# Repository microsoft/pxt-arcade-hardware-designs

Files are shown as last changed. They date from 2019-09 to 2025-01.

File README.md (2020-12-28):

# MakeCode Arcade Hardware Designs

This repository houses hardware reference design information for MakeCode Arcade devices. See https://arcade.makecode.com/hardware/adding for more information.

# Project List

- ArcadeMVD-STM: Standalone MakeCode Arcade gaming console based on STM32F4
- microbit-shield: MakeCode Arcade 'shield' for use with micro:bit V2

# Contributing

This project welcomes contributions and suggestions.  Most contributions require you to agree to a
Contributor License Agreement (CLA) declaring that you have the right to, and actually do, grant us
the rights to use your contribution. For details, visit https://cla.microsoft.com.

When you submit a pull request, a CLA-bot will automatically determine whether you need to provide
a CLA and decorate the PR appropriately (e.g., label, comment). Simply follow the instructions
provided by the bot. You will only need to do this once across all repos using our CLA.

This project has adopted the [Microsoft Open Source Code of Conduct](https://opensource.microsoft.com/codeofconduct/).
For more information see the [Code of Conduct FAQ](https://opensource.microsoft.com/codeofconduct/faq/) or
contact [opencode@microsoft.com](mailto:opencode@microsoft.com) with any additional questions or comments.

# Legal Notices

Microsoft and any contributors grant you a license to the Microsoft documentation and other content
in this repository under the [Creative Commons Attribution 4.0 International Public License](https://creativecommons.org/licenses/by/4.0/legalcode),
see the [LICENSE](LICENSE) file, and grant you a license to any code in the repository under the [MIT License](https://opensource.org/licenses/MIT), see the
[LICENSE-CODE](LICENSE-CODE) file.

Microsoft, Windows, Microsoft Azure and/or other Microsoft products and services referenced in the documentation
may be either trademarks or registered trademarks of Microsoft in the United States and/or other countries.
The licenses for this project do not grant you rights to use any Microsoft names, logos, or trademarks.
Microsoft's general trademark guidelines can be found at http://go.microsoft.com/fwlink/?LinkID=254653.

Privacy information can be found at https://privacy.microsoft.com/en-us/

Microsoft and any contributors reserve all others rights, whether under their respective copyrights, patents,
or trademarks, whether by implication, estoppel or otherwise.

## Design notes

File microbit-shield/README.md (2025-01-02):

Picture of micro:bit MakeCode Arcade shield (https://youtu.be/uZcsJYvYL_I)

# MakeCode Arcade Shield for micro:bit V2 Specification

**Preliminary, untested design; see below for more details. License: CC-BY 4.0.**

Thank you for your interest in building a [MakeCode Arcade](https://arcade.makecode.com/)
shield for the [new micro:bit V2](https://tech.microbit.org/latest-revision/announcement/).
We hope that you are as excited as we are to bring a wealth of new experiences to users of micro:bit V2 and MakeCode Arcade.

**Arcade Shields will work only with micro:bit V2**; they will not work with the original micro:bit V1.

To enable a diverse ecosystem of Arcade shields for the micro:bit V2 while maintaining a cohesive user experience, 
it is important to standardize software and hardware interfaces.
We have therefore produced a specification along with hardware and firmware reference designs that describe the compatibility
requirements for a MakeCode Arcade display shield for micro:bit V2.
Any shield that is produced must be approved by Microsoft and The Micro:bit Educational Foundation before
it will be publicly listed.

A [PDF schematic](https://raw.githubusercontent.com/microsoft/pxt-arcade-hardware-designs/master/microbit-shield/MicroBitArcadeShieldMVD%2008-1.2.PDF)
of our hardware reference design is available in this folder.
If you view this with Adobe Reader
then clicking on the symbol of each component in the design will show the manufacturer name and part number plus other
details. Other PDF viewing software may not support this feature.

The preliminary information here is provided as a request for comments:
please use the [discussions tab](https://github.com/microsoft/pxt-arcade-hardware-designs/discussions)
or [file an issue](https://github.com/microsoft/pxt-arcade-hardware-designs/issues) in this repo to provide further comments and feedback.

**NOTICE:
This information is provided “as-is”.
You bear the risk of using it.
Aspects of the specification may change without notice.
Microsoft makes no warranties, express or implied, with respect to the information provided here.**

Structure of this document:
- [Desired End-user Experience](#user-experience)
- [Two Ways to Implement an Arcade Shield](#types-shields)
- [Simple Shield Details](#hdw-config)
- [Power](#power)
- [Jacdac](#jacdac)
- [MCU Shield Details](#smart-shield)
- [Arcade Shield Testing](#testing)

## Desired End-user Experience

We want to create an intuitive, simple, reliable and engaging experience for end-users of MakeCode Arcade and micro:bit V2. A user first programs a game at https://arcade.makecode.com/, then clicks the Download
button, selects "micro:bit (V2) with shield" from the dialog (there is only one
entry for all micro:bit shields), and drops the resulting `.hex` file onto the `MICROBIT` drive of their micro:bit V2.
The user can plug their micro:bit V2 into an Arcade shield to play the game.

The micro:bit V2 can be also programmed when plugged into a shield, in which case batteries are not needed in the shield.

## Two Ways to Implement an Arcade Shield

There are two ways to implement an Arcade shield:
- A **simple shield**'s hardware components are all driven directly from the micro:bit V2; the shield itself has no additional microcontroller. The simple shield supports only 128x160 pixel ST7735/ILI9163C SPI screens, which are typically ~1.8" diagonal.
- An **MCU shield** or **smart shield** is fitted with a microcontroller (MCU) that provides a consolidated SPI interface to the micro:bit V2, and may drive a range of different screens including those with an 8-bit parallel connection. The micro:bit uses this SPI interface to update the shield’s display and to support other inputs and outputs such as buttons. MCU shield designers may choose to leverage additional capabilities of the on-shield MCU to attach additional peripherals via GPIOs, I2C or otherwise.

## Simple Shield Details

* [PDF schematics](https://raw.githubusercontent.com/microsoft/pxt-arcade-hardware-designs/master/microbit-shield/MicroBitArcadeShieldMVD%2008-1.2.PDF) of the reference design
* [Bill of Materials](https://github.com/microsoft/pxt-arcade-hardware-designs/blob/master/microbit-shield/BOM%20(complete%20design)%20MicroBitArcadeShieldMVD%2008-1.2.xlsx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)

As its name suggests, the design of a Simple Shield is straightforward. The micro:bit V2 edge connector 
SPI lines drive the display module directly, although simple low-pass RC filters are likely to be required 
on the SPI data and clock lines to reduce EMI. 
A discrete transistor is used to control the display backlight because a micro:bit GPIO would not be able to 
source the necessary current, ~45mA. 

To reduce the number of micro:bit GPIOs required to interface to
the Arcade control buttons, the reference design for the Simple Shield contains two parallel in, serial 
out shift registers (`INSR0` and `INSR1`). By being economical with micro:bit GPIOs, the three 'ring' GPIOs (P0, P1 and P2) are left available for users to connect to.

There are different variants of 128x160 pixel ST7735/ILI9163C SPI screens, so the MakeCode Arcade software stack needs to determine which is used by a
particular Arcade Shield and its orientation in order to perform the appropriate software configuration.
At power on, the MakeCode Arcade software stack inspects the upper most four bits of
the second input shift register (inputs `HW_CFG0` – `HW_CFG3` of `INSR1`) to determine hardware configuration.
A valid identifier stored in these bits allows the Arcade software stack to perform the appropriate software configuration.

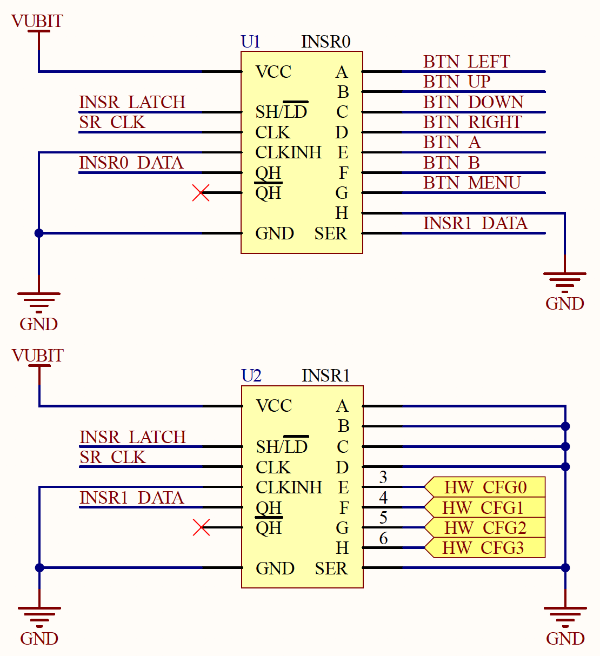
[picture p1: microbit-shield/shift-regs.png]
input shift registers picture


To set a `HW_CFGx` pin to a zero or one, it must be pulled low (to `GND`) or high (to `VUBIT`).
The reference design includes three-way solder jumpers for experimentation.
The tables below summarize the currently-supported hardware configuration identifiers.
If you would like to propose a new configuration please [file an issue in this repo](https://github.com/microsoft/pxt-arcade-hardware-designs/issues).

| `HW_CFG0` | Display rotation
|---:|---
| 0 | Display rotated 180 degrees; screen's flat-flex is on the left.
| 1 | Display not rotated; screen's flat-flex is on the right.

| `HW_CFG3` | `HW_CFG2` | `HW_CFG1` | Hardware configuration
|---:|---:|---:| ---
| 0 | 0 | 0 | Reserved, do not use
| 0 | 0 | 1 | ST7735 (`CFG1=0x603` or `CFG1=0x12c2d`; most common)
| 0 | 1 | 0 | ILI9163C with BGR color order (`CFG1=0xe14ff`)
| 0 | 1 | 1 | ST7735 with inverted color values (`CFG1=0x603`, `CFG0 = 0x1??????`)
| 1 | 0 | 0 | Future configuration (micro:bit will hang)
| 1 | 0 | 1 | Future configuration (micro:bit will hang)
| 1 | 1 | 0 | Future configuration (micro:bit will hang)
| 1 | 1 | 1 | Reserved, do not use

Our reference design includes two options for controlling the CS ('chip select') input on a typical SPI display such as one integrating an ST7735 controller IC. These options are selected via a solder-blob jumper, SB4 on the schematic. The simplest approach is to hard-wire CS to logic zero, so that the display is permanently enabled. However, in this case the display may be susceptible to latch-up as a result of an ESD event, and therefore may not pass EMC compliance testing. [Kitronik Ltd](https://kitronik.co.uk/) have kindly contributed an alternative approach to controlling the display's CS input, which causes the display to be automatically de-selected after every frame update and then re-selected a short time later, in time for the next frame of data. Kitronik's circuit ("Dynamic display enable generator" in the reference design) uses two monostable circuits, each consisting of a capacitor, transistor and some resistors. The first monostable is designed to introduce a ~20μs delay following the end of a burst of SPI clock activity, while the second is a ~5-10μs pulse generator that drives the CS input via a final transistor inverter.

## Power

The shield sources power directly from the micro:bit V2 when the micro:bit is powered from USB, 
whether connected to a USB power supply or connected to a computer.
When the micro:bit is not being powered from USB, a battery/batteries fitted to the shield can be used to power both shield and micro:bit.

In our reference design the shield incorporates 3x AA cells and a low dropout linear regulator to generate 3.3V. 
This passes through a 300mΩ series resistor to reduce the voltage to around 3.25V, depending on current draw.
(Conveniently there is already a 300mΩ ferrite on the design to reduce EMI, so we use a second of these rather 
than adding a new component to the BoM.)
Since the micro:bit will provide exactly 3.3V on its edge connector when powered from USB,
current for the shield will be sourced from this USB power when it is provided. But when the micro:bit is disconnected from USB power,
the shield's regulated battery supply of 3.25V will be used, giving users an uninterrupted experience as they move to on-the-go gaming.

The reference design draws no battery power if the micro:bit is not inserted into the Arcade shield.
This is achieved by connecting `VBAT_GND` to the shield’s `GND` through the micro:bit edge connector, so a circuit is completed only when a micro:bit has been inserted into the shield.

While the reference design uses 3x AA cells, alternative power sources such as rechargeable batteries are possible. Please be sure to meet all relevant safety and compliance guidelines. If using a detachable battery or battery pack, please use a connector that is different from the micro:bit 3V battery pack connector to avoid confusion and potential damage to the shield or micro:bit. **Please do not use batteries that can be swallowed, such as coin cells.** 

If the Arcade Shield does not have batteries fitted and the micro:bit is powered from 2xAA batteries (instead of via USB), at most 3.0V will be available, and without fresh batteries significantly less. This should be
avoided because shield operation will be unreliable; in particular the display backlight may not function correctly.

When a micro:bit is running a game and the Arcade shield screen is at full brightness the power draw should be ~45mA for a 1.8"
screen, ~100mA for a 2.4" screen and slightly more for 2.8" and 3.2" screens. When the micro:bit is disconnected from the shield no power is drawn.

## Jacdac

[Jacdac](https://aka.ms/jacdac) is a plug-and-play protocol and hardware/software stack for connecting microcontrollers and peripherals, developed by Microsoft and Lancaster University. Jacdac's flexible topology supports dynanic discovery and power delivery, thereby providing
an intuitive and low-cost way for users to extend their physical computing devices and projects with new hardware. 
Microsoft provides a first-class Jacdac experience in MakeCode that integrates the auto-detection, programming, simulation and operation of Jacdac devices.

Jacdac uses three wires to support 1Mbps half-duplex serial communications at 3.3V logic levels and power delivery of up to 1A at 5V. It uses a purpose-designed 3-pin PCB edge connector in conjunction with easy-to-use cables. It is a true bus topology that allows multiple devices to be connected directly to the same bus, but unlike I2C all devices have unique IDs.

When a micro:bit is plugged into an Arcade shield, the micro:bit edge connector is no longer available
for other accessories. However, it's still possible to support a physical computing experience if the Arcade shield supports Jacdac.
For this reason, the reference design includes two [Jacdac edge connectors](https://github.com/microsoft/jacdac-mdk/tree/main/connector). 
Users of shields that include Jacdac support will be able to use commercially-available Jacdac modules.

A set of [specifications](https://microsoft.github.io/jacdac-docs/ddk/) and [reference designs](https://github.com/microsoft/jacdac-ddk) for building Jacdac modules is availalbe.

To support the Jacdac experience, the Arcade shield requires additional components, as indicated in the reference design. 
Minimally, three diodes, a capacitor, a resistor and a ferrite bead are needed to support Jacdac communications. However,
for the best user experience an additional low-cost DC-DC converter and low-cost current limiter (plus support circuitry) 
can be included. These components allow the Arcade shield to safely and reliably provide power to the Jacdac bus. 
This in turn allows end users
to plug in sensor, display and actuator modules without worrying about power.

Power delivered to the Jacdac bus is always controlled by a current limiting circuit. For the Arcade shield we suggest
using one of several readily-available and low-cost 75mA (typical) current limiter ICs since these are a good match with
the supply available from the micro:bit. These ICs have an absolute maximum current limit of up to 100mA. 
The voltage at the Jacdac PCB edge connector on the Arcade shield must be between 
3.67V (absolute minimum) and 5.5V (absolute maximum) when the current can reach a maximum of 100 mA. For lower maximum currents, a lower minimum voltage is permissible, see [Vout_pp](https://microsoft.github.io/jacdac-docs/reference/electrical-spec/#power-providers). 
In our reference design, which uses a Schottky diode to prevent back-powering, in order to ensure at least 3.67V at the Jacdac connector, the input to the current limiter must be at least 3.88V. It is possible to supply power from 3x AA batteries but note that when they fall below ~1.3V each the device will be out of spec for a 100mA Jacdac power provider. It is also possible to supply power from a LiPo battery but again, when its terminal voltage falls below 3.88V it will be out of spec for delivering 100mA. An ideal diode with a lower forward voltage drop than the Schottky diode in our reference design will provide more margin. Note that **a current limiter must be used** in all cases.

It is also possible for an Arcade display shield to provide in excess of 100mA, which must be done 
at a slightly higher voltage, again please refer to [Vout_pp](https://microsoft.github.io/jacdac-docs/reference/electrical-spec/#power-providers). In this case **the shield must contain a microcontroller running the [Jacdac power service](https://microsoft.github.io/jacdac-docs/services/power/)**.  

## MCU Shield Details

An MCU Shield contains an MCU that interfaces with the attached micro:bit V2 using
a form of the [Jacdac protocol](https://aka.ms/jacdac), run over SPI.
It exposes at least two Jacdac services, one for driving the screen, and one for reading the buttons.
Additional services can be added for peripherals like vibration motors. The MCU Shield is therefore
more complicated to design and produce than the Simple Shield, but it supports more features, including larger screens.

The MCU Shield typically drives a 320x240 screen based on the ILI9341 chip, using an 8 bit parallel connection.
The Jacdac screen interface uses the Arcade's native 160x120 resolution and 4 bit indexed color depth, 
so the 4MHz SPI bus between the shield and the micro:bit is enough to obtain smooth frame rates.
The Shield MCU up-scales to 320x240 and converts from 
4 bit color to the 12, 16 or 18 bit RGB color typically used by the screens.
Other controller chips (such as S6D0154, ILI9325, ST7789) can by supported
with slight modifications of the MCU firmware. With more extensive firmware modification yet more
screen configurations are possible.
It's even possible to connect to an ST7735 controller over SPI, with all of that being abstracted by the Jacdac screen interface.
We have prototyped MCU Shields with some of these configurations.

An MCU Shield requires no input shift registers,
instead the micro:bit edge connector pin allocated to `INSR0_DATA` must be pulled high while the MakeCode Arcade software stack initializes the shield MCU.
This results in the MakeCode Arcade software stack reading a sequence of sixteen ones, which indicates that an MCU Shield is connected.
Additional detection and configuration will then take place over SPI from the micro:bit.

### Reference Firmware Designs

We provide MCU Shield reference firmware for the STM32F030 chips (popular ones include STM32F030K6, STM32F030C6 and STM32F030C8).
The 8-bit parallel connection is bit-banged, so STM32F030x6 can be used.
The firmware can be easily adapted to STM32F031, STM32G030, STM32G031 and possibly others.
If you want to drive a 1.77" ST7735 via SPI note that only STM32G03x and STM32F030C8 have dual SPI.

The reference firmware can be found at https://github.com/microsoft/pxt-arcade-smart-shield.
There are instructions for building and modifying it in the firmware repository.

### Reference Hardware Designs

The [PDF file](https://raw.githubusercontent.com/microsoft/pxt-arcade-hardware-designs/master/microbit-shield/smart-shield-v0.0.1.pdf) 
in this folder shows changes between the Simple and MCU Shields in schematic form.
Essentially:
* the input shift registers are replaced with an MCU, which is then connected to the screen;
* button pull-ups are removed sicne the MCU has internal pull-ups;
* more pins are left free on the edge connector, including the SCL/SDA pins;
* the circuity for the power supply, JACDAC, and the external P0, P1 and P2 rings stays the same.

You will also need to connect an SWD debugger so that you can program the shield with firmware.
You may want to use [our debug connector](https://arcade.makecode.com/hardware/dbg), but of course you can also use something else.

The schematic lists STM32F030C6 but the C8 variant (different flash size) can be also used.
If you use STM32F030K6, which hase 32 pins instead of the C6's 48 pins, ignore the `LOGx` pins and hard-wire `DISPLAY_CS` low and `DISPLAY_RD` high, as shown in the schematics. All the other pins necessary for building a shield are available on the K6 version of the chip.

### Extensions

In addition to supporting larger screens, another advantage of the MCU Shield approach is that hardware and software extensions are possible. None are supported by MakeCode Arcade yet, but if you want to implement any of the following, or have ideas for others, please
[let us know](https://github.com/microsoft/pxt-arcade-hardware-designs/discussions).
Note that these extensions are only possible for the MCU Shield
and are exposed through the Jacdac protocol running over the consolidated SPI connection.

* An analog joystick instead of directional buttons:
  you will need to use `pressure_level` field in the Arcade Controls service.
* A vibration motor for haptic feedback: see the [vibration service](https://github.com/microsoft/jacdac/blob/main/services/vibration.md).

## Arcade Shield Testing

### Testing Basic Operation

* Go to https://arcade.makecode.com/beta?hw=n3.
* Select a game such as "Space Destroyer" from the "Block Games" row, select "Open Example" and click "Download" to download a `.hex` file.
* Connect a micro:bit to your computer via USB and copy the `.hex` file to it.
* Disconnect the USB cable and plug the micro:bit into a battery-powered Arcade shield - the game should start within a second.
* Remove the Arcade shield batteries and connect the micro:bit to USB power. After resetting the micro:bit the game should be running.
* Plug the micro:bit into a battery-powered shield while it is still connected to USB, press reset and the game should start.

### Additional Testing

Jacdac connectors that support power delivery should be tested to ensure that the power delivered to the bus is current limited as specified, 
that the limiting resets automatically, and that the bus voltage is within spec at all times. The allowable voltage range for a power delivery 
device that supports up to 100mA is 3.67 - 5.5V; remember to allow for voltage measurement tolerance. No components should become hot to the touch
at any point.

Additional design verification and validation testing of the shield will likely be necessary.

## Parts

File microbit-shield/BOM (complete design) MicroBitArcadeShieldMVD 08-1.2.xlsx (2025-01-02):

Bill of materials for costing | Microsoft Research |  | Arcade shield reference design for the BBC micro:bit V2
Source Data From: | MicroBitArcadeShieldMVD 08.PrjPCB |  | Bill of Materials for Project [MicroBitArcadeShieldMVD 08.PrjPCB] (No PCB Document Selected)
Project filename: | MicroBitArcadeShieldMVD 08.PrjPCB
Project codename/board ID: | MicroBitArcadeShieldMVD | 08
Variant/version: | None | 1.2
Creation Date: | 26/12/2024 | 16:00
Print Date: | 2024-12-26 | 16:00:22
Pricing based on number of boards = | 1000
Currency | USD
Description | Manufacturer | Manufacturer Part Number | Designator | Quantity | Order Quantity | Best Supplier | Best Supplier PN | Best Unit Price | Best Subtotal | Supplier 1 | Supplier Part Number 1 | Supplier Unit Price 1 | Supplier Subtotal 1 | Supplier 2 | Supplier Part Number 2 | Supplier Unit Price 2 | Supplier Subtotal 2 | Supplier 3 | Supplier Part Number 3 | Supplier Unit Price 3 | Supplier Subtotal 3 | #Column Name Error:' Supplier 4 | #Column Name Error:' Supplier Part Number 4 | #Column Name Error:' Supplier Unit Price 4 | #Column Name Error:' Supplier Subtotal 4
Battery Holder; AA; Polypropylene; PC Mount; 3; Spring; PC | Keystone Electronics | 2464 | B1 | 1 | 1000 | Farnell | 1704231 | 1.01 | 1010.00 | Digi-Key | 2464K-ND | 1.51 | 1505.25 | Farnell | 1704231 | 1.01 | 1010.00 | Mouser | 534-2464
Generic 10uF 10V 0603 X5R cap, e.g. Samsung CL10A106KP8NNNC | Samsung | CL10A106KP8NNNC | C1, C2 | 2 | 2000 | Digikey | 1276-1192-1-ND | 0.03 | 59.20 | Digikey | 1276-1192-1-ND | 0.03 | 59.20 | Mouser | 187-CL10A106KP8NNNC | 0.04 | 74.00 | Farnell | 3013386 | 0.04 | 72.75
Generic 0603 capacitor | Generic |  | C3, C4, C5, C8, C10, C13, C14 | 7 | 7000 | #N/A | #N/A | #N/A
Generic 4.7uF 10V X5R 0603 cap, e.g. Samsung CL10A475KP8NNNC | Samsung | CL10A475KP8NNNC | C6, C7, C9, C11, C12 | 5 | 5000 | Farnell | 3010071 | 0.01 | 43.90 | DigiKey | 1276-1044-1-ND | 0.01 | 52.00 | Farnell | 3010071 | 0.01 | 43.90
DIODE ARRAY SCHOTTKY 30V SOT23 | Nexperia | BAT54S,235 | D1, D2 | 2 | 2000 | Mouser | 771-BAT54S235 | 0.03 | 52.42 | Digikey | 1727-1868-1-ND |  |  | Mouser | 771-BAT54S235 | 0.03 | 52.42 | Rs | 1707990 | 0.03 | 60.00
DIODE SCHOTTKY 20V 1A SOD123FL | ON Semiconductor | MBR120VLSFT3G | D4, D5 | 2 | 2000 | Mouser | 863-MBR120VLSFT3G | 0.20 | 410.00 | Digikey | MBR120VLSFT3GOSCT-ND |  |  | Mouser | 863-MBR120VLSFT3G | 0.20 | 410.00 | Rs | 1867479 | 0.21 | 412.74
ESD Suppressor, low parasitic capacitance.TVS DIODE 5.5V 13V DFN1006-2 | Diodes | D5V0P1B2LP-7B | D6 | 1 | 1000 | Digikey | D5V0P1B2LP-7BDICT-ND | 0.04 | 39.00 | Digikey | D5V0P1B2LP-7BDICT-ND | 0.04 | 39.00 | Mouser | 621-D5V0P1B2LP-7B | 0.04 | 39.00
ESD Suppressor, low parasitic capacitance.TVS DIODE 5.5V 13V DFN1006-2 | Diodes | D5V0P1B2LP-7B | D7, D8 | 2 | 2000 | Mouser | 621-D5V0P1B2LP-7B | 0.04 | 75.00 | Digikey | D5V0P1B2LP-7BDICT-ND | 0.04 | 78.00 | Mouser | 621-D5V0P1B2LP-7B | 0.04 | 75.00
0603 1k@100MHz 0.8A chip | TDK | MPZ1608S102ATA00 | FB1, FB2 | 2 | 2000 | Digi-Key | 445-8694-1-ND | 0.03 | 50.00 | Digi-Key | 445-8694-1-ND | 0.03 | 50.00 | Mouser | 810-MPZ1608S102ATA00
"Same plane" 1x40p 1.27mm Dongguan Yuliang BBC micro:bit edge connector | Dongguan Yuliang | MIC127-140-D01 | J1 | 1 | 1000 | #N/A | #N/A | #N/A
Inductor, Shielded, 10uH, 600mA, SMD; NRH Series; Inductance:10 H; Inductance Tolerance: 20%; Inductor Construction:Shielded; DC Resistance Max:0.35ohm; RMS Current (Irms):620mA; Saturation Current (Isat):600mA ;RoHS Compliant: Yes | Taiyo Yuden | NRH3010T100MN | L1 | 1 | 1000 | Mouser | 963-NRH3010T100MN | 0.12 | 121.00 | Digikey | 587-2575-1-ND | 0.12 | 122.06 | Mouser | 963-NRH3010T100MN | 0.12 | 121.00
128x160 backlit colour LCD | Truly Semiconductor | JD-T18003-T01 | LCD1 | 1 | 1000 | #N/A | #N/A | #N/A |  | Digi-Key | 1528-2562-ND |  |  | Mouser | 485-618 |  |  | Adafruit | 618
2N7002NXAK - 60 V, single N-channel Trench MOSFET | Nexperia | 2N7002NXAKR | Q1 | 1 | 1000 | Mouser | 771-2N7002NXAKR | 0.03 | 28.00 | Digikey | 1727-8643-1-ND | 0.03 | 34.11 | Farnell | 3226400 | 0.03 | 28.85 | Mouser | 771-2N7002NXAKR | 0.03 | 28.00
TR_NPN | On Semi | MMBT3904 | Q2, Q3, Q4 | 3 | 3000 | #N/A | #N/A | #N/A
Generic 0603 resistor | Generic |  | R1, R2, R3, R4, R5, R6, R7, R8, R9, R10, R11, R12, R13, R14 | 14 | 14000 | #N/A | #N/A | #N/A
Res Thick Film Array 330K Ohm 5% 200ppm/C ISOL Molded 8-Pin 1206(4 X 0603) Convex SMD Punched Carrier T/R | Panasonic | EXB-38V334JV | RP1, RP2 | 2 | 2000 | Digikey | Y9334CT-ND | 0.02 | 36.00 | Digikey | Y9334CT-ND | 0.02 | 36.00 | Mouser | 667-EXB-38V334JV | 0.02 | 45.10
6x6mm SPST 0.05A 12VDC SMD 260gf | Wurth Electronics | 430152050826 | SW1, SW2, SW3, SW4, SW5, SW6, SW7 | 7 | 7000 | Farnell | 2065110 | 0.37 | 2570.40 | Digikey | 732-6993-1-ND | 0.46 | 3204.92 | Farnell | 2065110 | 0.37 | 2570.40 | RSComponents | 7856213
8-BIT SHIFT/LOAD (INPUT) REGISTER, 16-SOIC |  |  | U1, U2 | 2 | 2000 | Digikey | 296-8250-1-ND | 0.09 | 183.36 | Digikey | 296-8250-1-ND | 0.09 | 183.36 | Mouser | 595-SN74HC165DR | 0.09 | 184.00 | RSComponents | 526640
IC REG BST ADJ 0.22A SYNC SOT23 |  |  | U3 | 1 | 1000 | Digikey | 296-30547-1-ND | 0.42 | 418.77 | Digikey | 296-30547-1-ND | 0.42 | 418.77 | Farnell | 3007284 | 0.42 | 419.00 | Mouser | 595-TLV61220DBVR
POWER LOAD SWITCH, HIGH SIDE, SOT-23-6; Power Load Switch Type:High Side; Input Voltage:6.5V; Current Limit:1.7A; On State Resistance:0.085ohm; Distribution Switch Case Style:SOT-23; No. of Pins:6; Thermal Protection:Yes; On / Enable;RoHS Compliant: Yes |  |  | U4 | 1 | 1000 | DigiKey | 296-32464-1-ND | 0.39 | 386.48 | DigiKey | 296-32464-1-ND | 0.39 | 386.48 | Farnell | 3124082 | 0.39 | 387.00 | Mouser | 595-TPS2553DBVR
ON SEMICONDUCTOR - NCP114ASN330T1G - LDO Voltage Regulator, Fixed, 1.7 V to 5.5 V in, 3.3 V/300 mA out, 150 mV drop, TSOP-5 | ON Semiconductor | NCP114ASN330T1G | U5 | 1 | 1000 | Rs | 1263178 | 0.09 | 90.00 | Digikey | NCP114ASN330T1GOSCT-ND | 0.18 | 175.61 | Rs | 1263178 | 0.09 | 90.00 | Mouser | 863-NCP114ASN330T1G | 0.11 | 107.64
number of line items | 21 |  | total | 59 | 59000 |  | total |  | 5573.53
 |  |  |  |  |  |  | unit price |  | 5.57

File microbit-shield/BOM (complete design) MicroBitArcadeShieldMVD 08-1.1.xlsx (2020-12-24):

Bill of materials for costing | Microsoft Research |  | Arcade shield reference design for the BBC micro:bit V2
Source Data From: | MicroBitArcadeShieldMVD 08.PrjPCB |  | Bill of Materials for Project [MicroBitArcadeShieldMVD 08.PrjPCB] (No PCB Document Selected)
Project filename: | MicroBitArcadeShieldMVD 08.PrjPCB
Project codename/board ID: | MicroBitArcadeShieldMVD | 08
Variant/version: | None | 1.1
Creation Date: | 24/12/2020 | 13:08
Print Date: | 2020-12-24 | 13:08:40
Pricing based on number of boards = | 1000
Currency | USD
Description | Manufacturer | Manufacturer Part Number | Designator | Quantity | Order Quantity | Best Supplier | Best Supplier PN | Best Unit Price | Best Subtotal | Supplier 1 | Supplier Part Number 1 | Supplier Unit Price 1 | Supplier Subtotal 1 | Supplier 2 | Supplier Part Number 2 | Supplier Unit Price 2 | Supplier Subtotal 2 | Supplier 3 | Supplier Part Number 3 | Supplier Unit Price 3 | Supplier Subtotal 3 | #Column Name Error:' Supplier 4 | #Column Name Error:' Supplier Part Number 4 | #Column Name Error:' Supplier Unit Price 4 | #Column Name Error:' Supplier Subtotal 4
Battery Holder; AA; Polypropylene; PC Mount; 3; Spring; PC | Keystone Electronics | 2464 | B1 | 1 | 1000 | Mouser | 534-2464 | 0.63 | 632.00 | Digi-Key | 2464K-ND | 1.62 | 1618.00 | Farnell | 1704231 |  |  | Mouser | 534-2464 | 0.63 | 632.00
Generic 10uF 10V 0603 X5R cap, e.g. Samsung CL10A106KP8NNNC | Samsung | CL10A106KP8NNNC | C1, C2 | 2 | 2000 | Digi-Key | 1276-1192-1-ND | 0.04 | 81.00 | Digi-Key | 1276-1192-1-ND | 0.04 | 81.00 | Mouser | 187-CL10A106KP8NNNC | 0.04 | 82.00 | Farnell | 3013386 | 0.05 | 90.88
Generic 0603 capacitor | Generic |  | C3, C4, C5, C8, C10 | 5 | 5000 | #N/A | #N/A | #N/A
Generic 4.7uF 10V X5R 0603 cap, e.g. Samsung CL10A475KP8NNNC | Samsung | CL10A475KP8NNNC | C6, C7, C9, C11, C12 | 5 | 5000 | Digi-Key | 1276-1044-1-ND | 0.01 | 60.05 | Digi-Key | 1276-1044-1-ND | 0.01 | 60.05 | Farnell | 3010071 | 0.01 | 64.05
DIODE ARRAY SCHOTTKY 30V SOT23 | Nexperia | BAT54S,235 | D1, D2 | 2 | 2000 | Mouser | 771-BAT54S235 | 0.02 | 49.78 | Digi-Key | 1727-1868-1-ND |  |  | Mouser | 771-BAT54S235 | 0.02 | 49.78 | RSComponents | 1707990 | 0.03 | 58.00
DIODE SCHOTTKY 20V 1A SOD123FL | ON Semiconductor | MBR120VLSFT3G | D4, D5 | 2 | 2000 | RSComponents | 1867479 | 0.11 | 216.46 | Digi-Key | MBR120VLSFT3GOSCT-ND |  |  | Mouser | 863-MBR120VLSFT3G | 0.11 | 224.00 | RSComponents | 1867479 | 0.11 | 216.46
ESD Suppressor, low parasitic capacitance.TVS DIODE 5.5V 13V DFN1006-2 | Diodes | D5V0P1B2LP-7B | D7, D8 | 2 | 2000 | Mouser | 621-D5V0P1B2LP-7B | 0.05 | 91.02 | Digi-Key | D5V0P1B2LP-7BDICT-ND | 0.05 | 98.00 | Mouser | 621-D5V0P1B2LP-7B | 0.05 | 91.02
0603 1k@100MHz 0.8A chip | TDK | MPZ1608S102ATA00 | FB1, FB2 | 2 | 2000 | Digi-Key | 445-8694-1-ND | 0.02 | 49.40 | Digi-Key | 445-8694-1-ND | 0.02 | 49.40 | Mouser | 810-MPZ1608S102ATA00 | 0.03 | 50.00
"Same plane" 1x40p 1.27mm Dongguan Yuliang BBC micro:bit edge connector | Dongguan Yuliang | MIC127-140-D01 | J1 | 1 | 1000 | #N/A | #N/A | #N/A
Inductor, Shielded, 10uH, 600mA, SMD; NRH Series; Inductance:10 H; Inductance Tolerance: 20%; Inductor Construction:Shielded; DC Resistance Max:0.35ohm; RMS Current (Irms):620mA; Saturation Current (Isat):600mA ;RoHS Compliant: Yes | Taiyo Yuden | NRH3010T100MN | L1 | 1 | 1000 | Digi-Key | 587-2575-1-ND | 0.12 | 117.00 | Digi-Key | 587-2575-1-ND | 0.12 | 117.00 | Mouser | 963-NRH3010T100MN | 0.13 | 134.00
128x160 backlit colour LCD | Truly Semiconductor | JD-T18003-T01 | LCD1 | 1 | 1000 | Digi-Key | 1528-2562-ND | 9.95 | 9950.00 | Digi-Key | 1528-2562-ND | 9.95 | 9950.00 | Mouser | 485-618 | 9.95 | 9950.00 | Adafruit | 618
2N7002NXAK - 60 V, single N-channel Trench MOSFET | Nexperia | 2N7002NXAKR | Q1 | 1 | 1000 | Digi-Key | 1727-8643-1-ND | 0.02 | 17.40 | Digi-Key | 1727-8643-1-ND | 0.02 | 17.40 | Farnell | 3226400 | 0.02 | 19.96 | Mouser | 771-2N7002NXAKR | 0.02 | 18.00
Generic 0603 resistor | Generic |  | R1, R2, R3, R4, R5, R6, R7 | 7 | 7000 | #N/A | #N/A | #N/A
Res Thick Film Array 330K Ohm 5% 200ppm/C ISOL Molded 8-Pin 1206(4 X 0603) Convex SMD Punched Carrier T/R | Panasonic | EXB-38V334JV | RP1, RP2 | 2 | 2000 | Mouser | 667-EXB-38V334JV | 0.01 | 26.40 | Digi-Key | Y9334CT-ND | 0.01 | 28.00 | Mouser | 667-EXB-38V334JV | 0.01 | 26.40
Generic 6x6mm SPST button e,g, Wurth 430152050826 | Wurth Electronics | 430152050826 | SW1, SW2, SW3, SW4, SW5, SW6, SW7 | 7 | 7000 | Farnell | 2065110 | 0.38 | 2676.24 | Digi-Key | 732-6993-1-ND | 0.47 | 3284.53 | Farnell | 2065110 | 0.38 | 2676.24 | RSComponents | 7856213
8-BIT SHIFT/LOAD (INPUT) REGISTER, 16-SOIC | Texas Instruments | SN74HC165DR | U1, U2 | 2 | 2000 | Digi-Key | 296-8250-1-ND | 0.13 | 252.00 | Digi-Key | 296-8250-1-ND | 0.13 | 252.00 | Mouser | 595-SN74HC165DR |  |  | RSComponents | 526640 | 0.13 | 252.00
IC ADJ Dc-DC 0.22A SOT23 | Texas Instruments | TLV61220DBVR | U3 | 1 | 1000 | Mouser | 595-TLV61220DBVR | 0.41 | 407.00 | Digi-Key | 296-30547-1-ND | 0.42 | 420.00 | Farnell | 3007284 | 0.43 | 431.47 | Mouser | 595-TLV61220DBVR | 0.41 | 407.00
POWER LOAD SWITCH, HIGH SIDE, SOT-23-6; Power Load Switch Type:High Side; Input Voltage:6.5V; Current Limit:1.7A; On State Resistance:0.085ohm; Distribution Switch Case Style:SOT-23; No. of Pins:6; Thermal Protection:Yes; On / Enable;RoHS Compliant: Yes | Texas Instruments | TPS2553DBVR | U4 | 1 | 1000 | Digi-Key | 296-32464-1-ND | 0.36 | 364.00 | Digi-Key | 296-32464-1-ND | 0.36 | 364.00 | Farnell | 3124082 | 0.45 | 448.99 | Mouser | 595-TPS2553DBVR | 0.36 | 364.00
ON SEMICONDUCTOR - NCP114ASN330T1G - LDO Voltage Regulator, Fixed, 1.7 V to 5.5 V in, 3.3 V/300 mA out, 150 mV drop, TSOP-5 | ON Semiconductor | NCP114ASN330T1G | U5 | 1 | 1000 | Digi-Key | NCP114ASN330T1GOSCT-ND | 0.07 | 67.00 | Digi-Key | NCP114ASN330T1GOSCT-ND | 0.07 | 67.00 | RSComponents | 1263178 | 0.07 | 71.00 | Mouser | 863-NCP114ASN330T1G | 0.07 | 71.53
number of line items | 19 |  | total | 46 | 46000 |  | total |  | 15056.75
 |  |  |  |  |  |  | unit price |  | 15.06

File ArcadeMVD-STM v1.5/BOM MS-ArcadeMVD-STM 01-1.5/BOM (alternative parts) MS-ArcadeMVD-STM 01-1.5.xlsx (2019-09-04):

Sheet: Costing
Bill of Materials for Costing | Microsoft Research |  | MakeCode Arcade reference design for STM32F4
Source Data From: | ArcadeMVD-STM 01-1.5 alternative parts.SchDoc |  | alternative parts
Project filename: | ArcadeMVD-STM 01-1.5.PrjPCB
Project codename/board ID: | MS-ArcadeMVD-STM | 01
Variant/version: | None | 1.5
Creation Date: | 30/08/2019 | 15:25:57
Print Date: | 2019-08-30 | 15:26:20
Pricing based on number of boards = | 1000
Currency | USD
Description | Manufacturer | Manufacturer Part Number | Designator | Quantity | Order Quantity | Best Supplier | Best Supplier PN | Best Unit Price | Best Subtotal | Supplier 1 | Supplier Part Number 1 | Supplier Unit Price 1 | Supplier Subtotal 1 | Supplier 2 | Supplier Part Number 2 | Supplier Unit Price 2 | Supplier Subtotal 2 | Supplier 3 | Supplier Part Number 3 | Supplier Unit Price 3 | Supplier Subtotal 3 | Supplier 4 | Supplier Part Number 4 | Supplier Unit Price 4 | Supplier Subtotal 4
Schottky diode, 1A low Vf | MCC | MBRX120LF-TP | D2 | 1 | 1000 | Mouser | 833-MBRX120LF-TP | 0.11 | 108.00 | Farnell | 1924371 (https://octopart-clicks.com/click/altium?sku=1924371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) | 0.15 | 153.63 | Mouser | 833-MBRX120LF-TP (https://octopart-clicks.com/click/altium?sku=833-MBRX120LF-TP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) | 0.11 | 108.00 | Digi-Key | MBRX120LF-TPMSCT-ND (https://octopart-clicks.com/click/altium?sku=MBRX120LF-TPMSCT-ND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) | 0.11 | 108.15
USB micro B with TH anchors | Adam Tech | MCR-B-S-RA-SMT-CS5-T/R | J1 | 1 | 1000 | #N/A | #N/A | #N/A |  | Adam Tech | MCR-B-S-RA-SMT-CS5-T/R
3-way 3.5mm switched jack socket SMD R/A | Switchcraft | 35RASMT4BHNTRX | J3 | 1 | 1000 | Mouser | 502-35RASMT4BHNTRX | 0.71 | 711.00 | Farnell | 2914546 (https://octopart-clicks.com/click/altium?sku=2914546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) | 1.01 | 1014.42 | Mouser | 502-35RASMT4BHNTRX (https://octopart-clicks.com/click/altium?sku=502-35RASMT4BHNTRX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) | 0.71 | 711.00 | RSComponents | 7051490 (https://octopart-clicks.com/click/altium?sku=7051490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) | 1.98 | 1976.00 | Digi-Key | SC1488-1-ND (https://octopart-clicks.com/click/altium?sku=SC1488-1-ND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) | 0.88 | 877.80
3-way 3.5mm switched jack socket SMD R/A | CUI | SJ2-3593D-SMT-TR | J3 | 1 | 1000 | Mouser | 490-SJ2-3593D-SMT-TR | 0.66 | 661.00 | Mouser | 490-SJ2-3593D-SMT-TR (https://octopart-clicks.com/click/altium?sku=490-SJ2-3593D-SMT-TR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) | 0.66 | 661.00 | Digi-Key | CP-SJ2-3593D-SMT-CT-ND (https://octopart-clicks.com/click/altium?sku=CP-SJ2-3593D-SMT-CT-ND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) | 0.82 | 817.74
Male header, pitch 2 mm, 1x2 position | Shenzhen Cankemeng | 2001SMTM-2P | J6 | 1 | 1000 | #N/A | #N/A | #N/A |  | LCSC | C132500
Male header, pitch 2 mm, 1x2 position | JXT | WB200SW-02SR01 | J6 | 1 | 1000 | #N/A | #N/A | #N/A
ARM Cortex M4 MCU+FPU 512k Flash, 96k RAM, 84MHz, QFPN48 | STMicroelectronics | STM32F401CEU6 | U1 | 1 | 1000 | Digi-Key | 497-17427-ND | 2.91 | 2913.26 | Farnell | 2432105 (https://octopart-clicks.com/click/altium?sku=2432105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) | 3.00 | 2999.36 | Digi-Key | 497-17427-ND (https://octopart-clicks.com/click/altium?sku=497-17427-ND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) | 2.91 | 2913.26 | Mouser | 511-STM32F401CEU6 (https://octopart-clicks.com/click/altium?sku=511-STM32F401CEU6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) | 3.40 | 3400.00
13.9x5mm SMD Crystal | Fox Electronics | FOXSDLF/080-20 | X1 | 1 | 1000 | Mouser | 559-FOXSD080-20-LF | 0.15 | 147.00 | Farnell | 2063972 (https://octopart-clicks.com/click/altium?sku=2063972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) | 0.16 | 163.38 | RSComponents | 5476452 (https://octopart-clicks.com/click/altium?sku=5476452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) | 0.20 | 200.00 | Mouser | 559-FOXSD080-20-LF (https://octopart-clicks.com/click/altium?manufacturer=Fox%20Electronics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) | 0.15 | 147.00 | Digi-Key | 631-1010-1-ND (https://octopart-clicks.com/click/altium?sku=631-1010-1-ND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) | 0.20 | 201.90
number of line items | 8 |  | total | 8 | 8000 |  | total |  | 4540.26
 |  |  |  |  |  |  | unit price |  | 4.54

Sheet: Build
Bill of Materials for Build Microsoft Research |  |  |  |  |  | ArcadeMVD-STM 01-1.5 alternative parts.SchDoc
 |  | 30/08/2019 |  |  | 15:25:57
8
# | Bin | LibRef | Footprint | #Column Name Error:PCB Feature | #Column Name Error:Fitted | #Column Name Error:link | Designator
1 |  | MCC MBRX120LF | MCC SOD-123 |  |  |  | D2
2 |  | MCR-B-S-RA-SMT-CS5-T/R-whitesch | MCR-B-S-RA-SMT-CS5-T/R |  |  |  | J1
3 |  | 35RASMT4BHNTRX | SWIT-35RASMT4BHNTRX_V |  |  |  | J3
4 |  | SJ2-3593D-SMT | SJ-3593D-SMT-TR |  |  |  | J3
5 |  | 2001SMTM-2P | JST- S2B-PH-SM4-TB(LF)(SN)-2_V |  |  |  | J6
6 |  | WB200SW-02SR01 | JST- S2B-PH-SM4-TB(LF)(SN)-2_V |  |  |  | J6
7 |  | ST STM32F401CEU6 | ST UFQFPN48 SEH |  |  |  | U1
8 |  | FOXSDLF/080-20 | FOX-HC49SDLF_V |  |  |  | X1

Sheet: Project Information
Project Full Path | D:\shodges\TFS-MSR\SenDev\Projects\EduBoards - MS\ArcadeMVD\Altium\ArcadeMVD-STM v1.5 RTM\ArcadeMVD-STM 01-1.5.PrjPCB
Project Filename | ArcadeMVD-STM 01-1.5.PrjPCB
Variant Name | None
Data-Source Filename | ArcadeMVD-STM 01-1.5 alternative parts.SchDoc
Data-Source Full Path | D:\shodges\TFS-MSR\SenDev\Projects\EduBoards - MS\ArcadeMVD\Altium\ArcadeMVD-STM v1.5 RTM\ArcadeMVD-STM 01-1.5 alternative parts.SchDoc
Title | alternative parts
Total Quantity | 8
Report Time | 15:25:57
Report Date | 30/08/2019
Report Date & Tine | 30/08/2019 15:25:57
Output Name | Bill of Materials
Output Type | BOM_PartType
Output Generator Name | BOM
Output Generator Description | Bill of Materials

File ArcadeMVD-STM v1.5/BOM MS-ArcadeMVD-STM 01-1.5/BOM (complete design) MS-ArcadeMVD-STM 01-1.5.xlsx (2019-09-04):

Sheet: Costing
Bill of Materials for Costing | Microsoft Research |  | MakeCode Arcade reference design for STM32F4
Source Data From: | ArcadeMVD-STM 01-1.5 complete design.SchDoc |  | complete design
Project filename: | ArcadeMVD-STM 01-1.5.PrjPCB
Project codename/board ID: | MS-ArcadeMVD-STM | 01
Variant/version: | None | 1.5
Creation Date: | 30/08/2019 | 15:27:43
Print Date: | 2019-08-30 | 15:28:34
Pricing based on number of boards = | 1000
Currency | USD
Description | Manufacturer | Manufacturer Part Number | Designator | Quantity | Order Quantity | Best Supplier | Best Supplier PN | Best Unit Price | Best Subtotal | Supplier 1 | Supplier Part Number 1 | Supplier Unit Price 1 | Supplier Subtotal 1 | Supplier 2 | Supplier Part Number 2 | Supplier Unit Price 2 | Supplier Subtotal 2 | Supplier 3 | Supplier Part Number 3 | Supplier Unit Price 3 | Supplier Subtotal 3 | Supplier 4 | Supplier Part Number 4 | Supplier Unit Price 4 | Supplier Subtotal 4
Generic 4.7uF 10V 0603 cap, e.g. Samsung CL10A475KP8NNNC | Samsung | CL10A475KP8NNNC | C1, C2, C3 | 3 | 3000 | Digi-Key | 1276-1044-1-ND | 0.03 | 85.80 | Digi-Key | 1276-1044-1-ND (https://octopart-clicks.com/click/altium?sku=1276-1044-1-ND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) | 0.03 | 85.80 | Farnell | 3010071 (https://octopart-clicks.com/click/altium?sku=3010071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)
Generic 0402 Chip Capacitor 12pF |  |  | C4, C5 | 2 | 2000 | #N/A | #N/A | #N/A
Generic 100nF 16V 0402 cap e.g. Kyocera/AVX 0402YG104ZAT2A | Kyocera AVX | 0402YG104ZAT2A | C6, C7, C8, C9, C12, C13 | 6 | 6000 | Farnell | 1327667 | 0.01 | 45.36 | Farnell | 1327667 (https://octopart-clicks.com/click/altium?sku=1327667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) | 0.01 | 45.36 | Digi-Key | 478-1138-1-ND (https://octopart-clicks.com/click/altium?sku=478-1138-1-ND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) | 0.01 | 51.48 | Mouser | 581-040216G104Z (https://octopart-clicks.com/click/altium?sku=581-040216G104Z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) | 0.01 | 48.00 | RSComponents | 698-3190
Generic 0402 Chip Capacitor 33pF |  |  | C10, C14, C15 | 3 | 3000 | #N/A | #N/A | #N/A
Schottky diode, 3A low Vf | Infineon | BAT60AE6327HTSA1 | D2 | 1 | 1000 | Farnell | 2432679 | 0.09 | 94.49 | Farnell | 2432679 (https://octopart-clicks.com/click/altium?sku=2432679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) | 0.09 | 94.49 | Mouser | 726-BAT60AE6327HTSA1 (https://octopart-clicks.com/click/altium?sku=726-BAT60AE6327HTSA1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) |  |  | RSComponents | 7527855 (https://octopart-clicks.com/click/altium?sku=7527855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) | 0.15 | 153.00 | Digi-Key | BAT60AE6327HTSA1CT-ND (https://octopart-clicks.com/click/altium?sku=BAT60AE6327HTSA1CT-ND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) | 0.12 | 115.98
USB TVS and ESD protection diodes | NXP Semiconductors | PRTR5V0U2X,215 | D3, D4 | 2 | 2000 | Mouser | 771-PRTR5V0U2X-T/R | 0.20 | 394.00 | Digi-Key | 1727-3884-1-ND (https://octopart-clicks.com/click/altium?sku=1727-3884-1-ND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) | 0.21 | 425.80 | RSComponents | 725-8720 (https://octopart-clicks.com/click/altium?sku=725-8720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) |  |  | Mouser | 771-PRTR5V0U2X-T/R (https://octopart-clicks.com/click/altium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) | 0.20 | 394.00 | Mouser | 771-PRTR5V0U2X-T/R
Generic 0603 Orange LED, e.g. Rohm SML-D12D8WT86 | Rohm Semiconductor | SML-D12D8WT86 | D5 | 1 | 1000 | Digi-Key | 511-1577-1-ND | 0.06 | 59.22 | Digi-Key | 511-1577-1-ND (https://octopart-clicks.com/click/altium?sku=511-1577-1-ND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) | 0.06 | 59.22
Schottky diode, 3A low Vf | Infineon | BAT60AE6327HTSA1 | D6, D7 | 2 | 2000 | Farnell | 2432679 | 0.09 | 188.98 | Farnell | 2432679 (https://octopart-clicks.com/click/altium?sku=2432679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) | 0.09 | 188.98 | Mouser | 726-BAT60AE6327HTSA1 (https://octopart-clicks.com/click/altium?sku=726-BAT60AE6327HTSA1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) |  |  | RSComponents | 7527855 (https://octopart-clicks.com/click/altium?sku=7527855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) | 0.15 | 306.00 | Digi-Key | BAT60AE6327HTSA1CT-ND (https://octopart-clicks.com/click/altium?sku=BAT60AE6327HTSA1CT-ND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) | 0.12 | 231.96
Generic 1206 resetable fuse 0.2A hold 0.4A trip e.g. Bel Fuse 0ZCJ0020FF2E | Bel | 0ZCJ0020FF2E | F1 | 1 | 1000 | Mouser | 530-0ZCJ0020FF2E | 0.05 | 50.00 | Farnell | 2848524 (https://octopart-clicks.com/click/altium?sku=2848524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) | 0.06 | 63.89 | Digi-Key | 507-1797-1-ND (https://octopart-clicks.com/click/altium?sku=507-1797-1-ND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) | 0.07 | 72.96 | Mouser | 530-0ZCJ0020FF2E (https://octopart-clicks.com/click/altium?sku=530-0ZCJ0020FF2E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) | 0.05 | 50.00
0603 1k@100MHz 0.8A chip | TDK | MPZ1608S102ATA00 | FB1 | 1 | 1000 | Digi-Key | 445-8694-1-ND | 0.03 | 27.17 | Digi-Key | 445-8694-1-ND (https://octopart-clicks.com/click/altium?sku=445-8694-1-ND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) | 0.03 | 27.17 | Mouser | 810-MPZ1608S102ATA00 (https://octopart-clicks.com/click/altium?sku=810-MPZ1608S102ATA00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) | 0.03 | 28.00
Micro USB SMD with TH mechanical mount | Hirose | ZX62D-B-5PA8(30) | J1 | 1 | 1000 | Mouser | 798-ZX62D-B-5PA830 | 0.36 | 363.00 | RSComponents | 1360893 (https://octopart-clicks.com/click/altium?sku=1360893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) | 555.03 | 555030.00 | Farnell | 2554981 (https://octopart-clicks.com/click/altium?sku=2554981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) | 0.41 | 410.89 | Mouser | 798-ZX62D-B-5PA830 (https://octopart-clicks.com/click/altium?sku=798-ZX62D-B-5PA830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) | 0.36 | 363.00 | Digi-Key | H125718CT-ND (https://octopart-clicks.com/click/altium?sku=H125718CT-ND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) | 0.40 | 399.30
Generic 3/4-way 3.5mm jack socket SMD R/A, e.g. CUI SJ2-3574A-SMT | CUI | SJ2-3574A-SMT-TR | J3 | 1 | 1000 | Mouser | 490-SJ2-3574A-SMT-TR | 0.58 | 578.00 | Mouser | 490-SJ2-3574A-SMT-TR (https://octopart-clicks.com/click/altium?sku=490-SJ2-3574A-SMT-TR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) | 0.58 | 578.00 | Digi-Key | CP-SJ2-3574A-SMT-CT-ND (https://octopart-clicks.com/click/altium?sku=CP-SJ2-3574A-SMT-CT-ND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) | 0.71 | 714.78
Generic male header, pitch 2 mm, 1x2 position, e.g. JST S2B-PH-SM4-TB(LF)(SN) | JST | S2B-PH-SM4-TB(LF)(SN) | J6 | 1 | 1000 | Digi-Key | 455-1749-1-ND | 0.36 | 364.70 | Digi-Key | 455-1749-1-ND (https://octopart-clicks.com/click/altium?sku=455-1749-1-ND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) | 0.36 | 364.70 | Farnell | 9492615 (https://octopart-clicks.com/click/altium?sku=9492615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) |  |  | RSComponents | 688-1353
Generic 128x160 backlit colour LCD, e.g. Truly Semi JD-T18003-T01 | Truly Semiconductor | JD-T18003-T01 | LCD1 | 1 | 1000 | Digi-Key | 1528-2562-ND | 9.95 | 9950.00 | Digi-Key | 1528-2562-ND (https://octopart-clicks.com/click/altium?sku=1528-2562-ND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) | 9.95 | 9950.00 | Mouser | 485-618 (https://octopart-clicks.com/click/altium?sku=485-618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) | 9.95 | 9950.00 | Adafruit | 618
Generic N-channel small signal MOSFET, e.g. On Semi 2N7002K | ON Semiconductor | 2N7002KT1G | Q1 | 1 | 1000 | Mouser | 863-2N7002KT1G | 0.04 | 38.00 | Farnell | 1764535 (https://octopart-clicks.com/click/altium?sku=1764535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) |  |  | Digi-Key | 2N7002KT1GOSCT-ND (https://octopart-clicks.com/click/altium?sku=2N7002KT1GOSCT-ND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) | 0.04 | 40.23 | Mouser | 863-2N7002KT1G (https://octopart-clicks.com/click/altium?sku=863-2N7002KT1G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) | 0.04 | 38.00 | RSComponents | 780-0478
MOSFET P-CH 20V 4.2A SOT23 | Diodes | DMG2305UX-13 | Q2 | 1 | 1000 | Farnell | 2543533 | 0.06 | 58.52 | Farnell | 2543533 (https://octopart-clicks.com/click/altium?sku=2543533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) | 0.06 | 58.52 | Mouser | 621-DMG2305UX-7 (https://octopart-clicks.com/click/altium?sku=621-DMG2305UX-7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) | 0.07 | 72.00 | RSComponents | 8270452 (https://octopart-clicks.com/click/altium?sku=8270452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) | 0.08 | 77.00 | Digi-Key | DMG2305UX-13DICT-ND (https://octopart-clicks.com/click/altium?sku=DMG2305UX-13DICT-ND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) | 0.07 | 73.80
Generic 0402 Chip Resistor 100k |  |  | R3, R6, R10 | 3 | 3000 | #N/A | #N/A | #N/A
Generic 0402 Chip Resistor 220R |  |  | R4 | 1 | 1000 | #N/A | #N/A | #N/A
Generic 0402 Chip Resistor 10R |  |  | R5, R8, R9 | 3 | 3000 | #N/A | #N/A | #N/A
Generic 0402 Chip Resistor 100R |  |  | R7 | 1 | 1000 | #N/A | #N/A | #N/A
Generic 6x6mm SPST button e,g, Wurth 430152050826 | Wurth Electronics | 430152050826 | SW1, SW2, SW3, SW4, SW5, SW6, SW7, SW8 | 8 | 8000 | #N/A | #N/A | #N/A |  | Farnell | 2065110 (https://octopart-clicks.com/click/altium?sku=2065110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) |  |  | Digi-Key | 732-6993-1-ND (https://octopart-clicks.com/click/altium?sku=732-6993-1-ND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) |  |  | RSComponents | 7856213 (https://octopart-clicks.com/click/altium?sku=7856213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)
ARM Cortex M4 MCU+FPU 512k Flash, 128k RAM, 100MHz, QFPN48 | STMicroelectronics | STM32F411CEU6 | U1 | 1 | 1000 | RSComponents | 1106616 | 2.86 | 2860.00 | RSComponents | 1106616 (https://octopart-clicks.com/click/altium?sku=1106616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) | 2.86 | 2860.00 | Farnell | 2456965 (https://octopart-clicks.com/click/altium?sku=2456965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) | 3.74 | 3743.10 | Digi-Key | 497-14907-ND (https://octopart-clicks.com/click/altium?sku=497-14907-ND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) | 2.94 | 2943.08 | Mouser | 511-STM32F411CEU6 (https://octopart-clicks.com/click/altium?sku=511-STM32F411CEU6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) | 3.92 | 3920.00
3.3V LDO | Exar | SPX3819M5-L-3-3/TR | U2 | 1 | 1000 | Digi-Key | 1016-1873-1-ND | 0.21 | 213.91 | Digi-Key | 1016-1873-1-ND (https://octopart-clicks.com/click/altium?sku=1016-1873-1-ND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) | 0.21 | 213.91 | Farnell | 2889625 (https://octopart-clicks.com/click/altium?sku=2889625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) | 0.24 | 236.53 | Mouser | 701-SPX3819M5-L-33TR (https://octopart-clicks.com/click/altium?sku=701-SPX3819M5-L-33TR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) | 0.22 | 224.00 | RSComponents | 8472888 (https://octopart-clicks.com/click/altium?sku=8472888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) | 0.34 | 343.00
Generic 3.2x2.5mm 24MHz 12pF SMD xtal, e.g. Multicomp MCSJK-7U-24.00-12-10-60-B-10 | Multicomp | MCSJK-7U-24.00-12-10-60-B-10 | X1 | 1 | 1000 | Farnell | 2853960 | 0.12 | 124.36 | Farnell | 2853960 (https://octopart-clicks.com/click/altium?sku=2853960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) | 0.12 | 124.36
number of line items | 24 |  | total | 47 | 47000 |  | total |  | 15495.51
 |  |  |  |  |  |  | unit price |  | 15.50

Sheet: Build
Bill of Materials for Build Microsoft Research |  |  |  |  |  | ArcadeMVD-STM 01-1.5 complete design.SchDoc
 |  | 30/08/2019 |  |  | 15:27:43
24
# | Bin | LibRef | Footprint | #Column Name Error:PCB Feature | #Column Name Error:Fitted | #Column Name Error:link | Designator
1 |  | 4.7uF 10V X5R ±10% Samsung CL | CAP 0603 (1608) x 1.2mm |  |  |  | C1, C2, C3
2 |  | CAP0402_GENERIC | CAP0402 |  |  |  | C4, C5
3 |  | 0402YG104ZAT2A | CAP0402 |  |  |  | C6, C7, C8, C9, C12, C13
4 |  | CAP0402_GENERIC | CAP0402 |  |  |  | C10, C14, C15
5 |  | BAT60AE6327HTSA1 | INF-SOD323_V |  |  |  | D2
6 |  | NXP-PRTR5V0U2X,215-4-whitesch | NXP-SOT143B-4_V |  |  |  | D3, D4
7 |  | SML-D12D | Rohm SML-D12 Orange |  |  |  | D5
8 |  | BAT60AE6327HTSA1 | INF-SOD323_V |  |  |  | D6, D7
9 |  | PTC Bel Fuse 0ZCJ0020FF2E | FUSE 1206 x 0.58mm |  |  |  | F1
10 |  | TDK MPZ1608S102ATA00 | TDK MPZ1608 0.8mm |  |  |  | FB1
11 |  | ZX62D-B-5PA8(30)-whitesch | HIRO-ZX62D-B-5PA8_V-noslots |  |  |  | J1
12 |  | SJ2-3574A-SMT | SJ2-3574A-SMT-TR-BASIC |  |  |  | J3
13 |  | S2B-PH-SM4-TB(LF)(SN) | JST-S2B-PH-SM4-TB |  |  |  | J6
14 |  | JD-T18003-T01 | JD-T18003-T01-BASIC |  |  |  | LCD1
15 |  | 2N7002K | ONSC-SOT-23-3-318-08_V |  |  |  | Q1
16 |  | DMG2305UX-whitesch | DIODES-SOT23-3 |  |  |  | Q2
17 |  | RES0402_GENERIC | RES0402 |  |  |  | R3, R6, R10
18 |  | RES0402_GENERIC | RES0402 |  |  |  | R4
19 |  | RES0402_GENERIC | RES0402 |  |  |  | R5, R8, R9
20 |  | RES0402_GENERIC | RES0402 |  |  |  | R7
21 |  | Tact Wurth 430152050826 | Wurth 430152050836-WIDE |  |  |  | SW1, SW2, SW3, SW4, SW5, SW6, SW7, SW8
22 |  | ST STM32F411CEU6 | ST UFQFPN48 SEH |  |  |  | U1
23 |  | SPX3819M5-L-3-3_TR | MaxLinear-SOT95P280X145-5N |  |  |  | U2
24 |  | 24MHz SMD xtal 3.2x2.5mm | generic xtal 3.2x2.5 |  |  |  | X1

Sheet: Project Information
Project Full Path | D:\shodges\TFS-MSR\SenDev\Projects\EduBoards - MS\ArcadeMVD\Altium\ArcadeMVD-STM v1.5 RTM\ArcadeMVD-STM 01-1.5.PrjPCB
Project Filename | ArcadeMVD-STM 01-1.5.PrjPCB
Variant Name | None
Data-Source Filename | ArcadeMVD-STM 01-1.5 complete design.SchDoc
Data-Source Full Path | D:\shodges\TFS-MSR\SenDev\Projects\EduBoards - MS\ArcadeMVD\Altium\ArcadeMVD-STM v1.5 RTM\ArcadeMVD-STM 01-1.5 complete design.SchDoc
Title | complete design
Total Quantity | 47
Report Time | 15:27:43
Report Date | 30/08/2019
Report Date & Tine | 30/08/2019 15:27:43
Output Name | Bill of Materials
Output Type | BOM_PartType
Output Generator Name | BOM
Output Generator Description | Bill of Materials

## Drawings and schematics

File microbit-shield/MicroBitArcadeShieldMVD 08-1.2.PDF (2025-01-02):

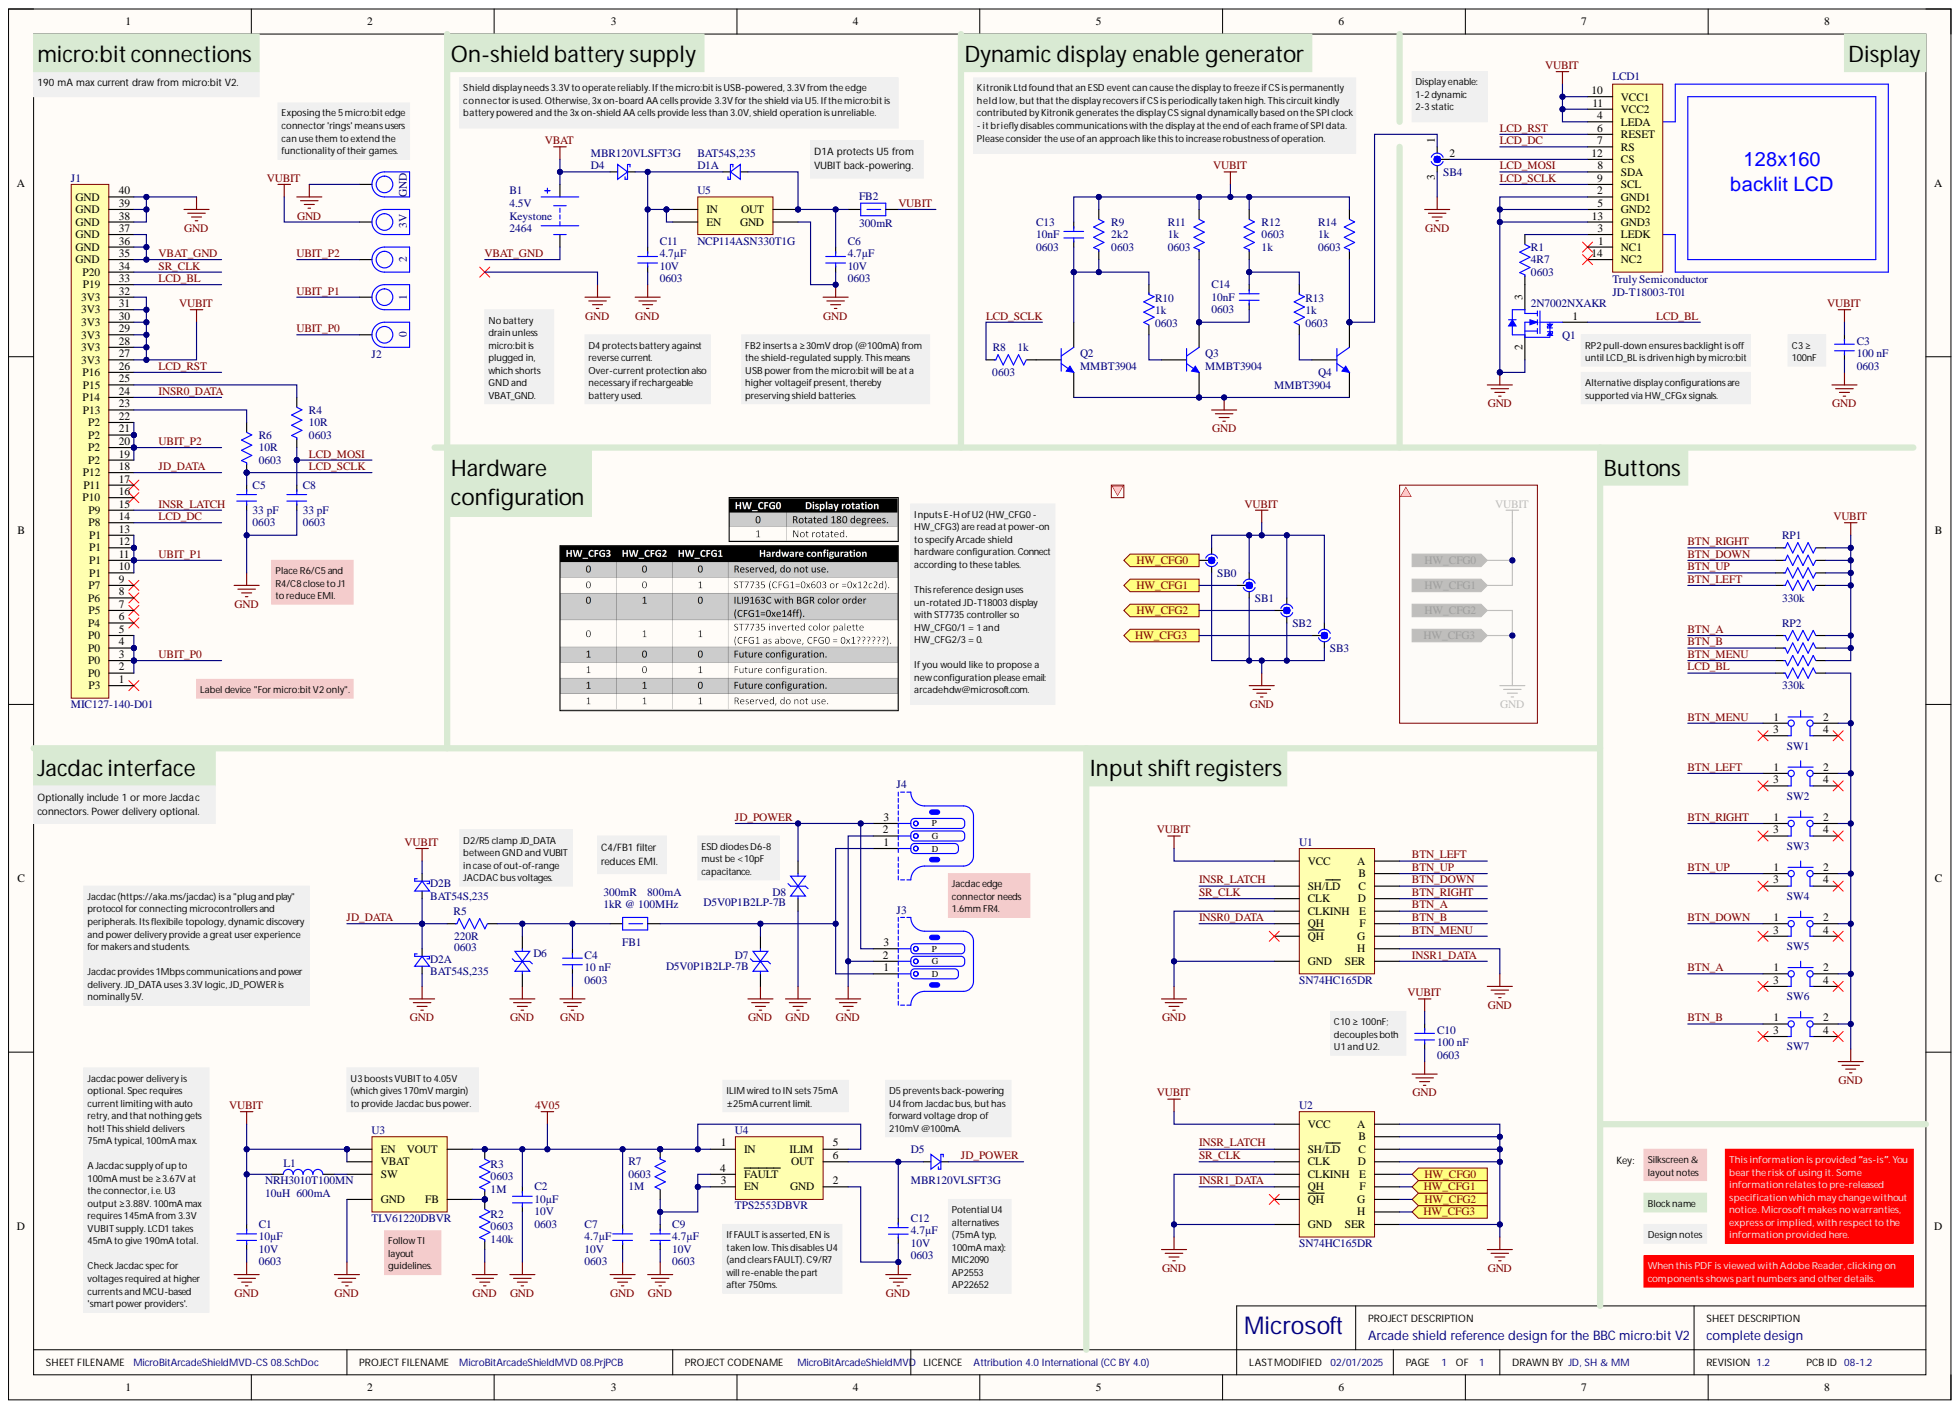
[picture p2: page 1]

Dynamic display enable generator

190 mA max current draw from micro:bit V2.

Shield display needs 3.3V to operate reliably. Ifthe micro:bit isUSB-powered, 3.3V from the edge
connector is used. Otherwise, 3x on-board AA cells provide 3.3V for the shield via U5. Ifthe micro:bit is
battery powered and the 3x on-shield AA cells provide less than 3.0V, shield operation is unreliable.

Kitronik Ltd found that an ESD event can cause the display to freeze if CS is permanently
held low, but that the display recovers if CS is periodically taken high. This circuit kindly
contributed by Kitronik generates the display CS signal dynamically based on the SPI clock
- it briefly disables communications with the display at the end of each frame of SPI data.
Please consider the use of an approach like this to increase robustness of operation.

Exposing the 5 micro:bit edge
connector 'rings' means users
can use them to extend the
functionality oftheir games.

RP2 pull-down ensures backlight is off
until LCD_BL is driven high by micro:bit

D4 protects battery against
reverse current.
Over-current protection also
necessary ifrechargeable
battery used.

FB2 inserts a ≥30mV drop (@100mA) from
the shield-regulated supply. This means
USB power from the micro:bit will be at a
higher voltageif present, thereby
preserving shield batteries.

Alternative display configurations are
supported via HW_CFGx signals.

Inputs E-H ofU2 (HW_CFG0 -
HW_CFG3) are read at power-on
to specify Arcade shield
hardware configuration. Connect
according to these tables.

This reference design uses
un-rotated JD-T18003 display
with ST7735 controller so
HW_CFG0/1 = 1 and
HW_CFG2/3 = 0.

If you would like to propose a
new configuration please email:
arcadehdw@microsoft.com.

Label device "For micro:bit V2 only".

Jacdac interface | J4 | Input shift registers

Optionally include 1 or more Jacdac connectors. Power delivery optional. | | VUBIT

D2/R5 clamp JD_DATA
between GND and VUBIT
in case of out-of-range
JACDAC bus voltages.

Jacdac (https://aka.ms/jacdac) is a "plug and play"
protocol for connecting microcontrollers and
peripherals. Its flexibile topology, dynamic discovery
and power delivery provide a great user experience
for makers and students.

Jacdac provides 1Mbps communications and power
delivery. JD_DATA uses 3.3V logic, JD_POWER is
nominally 5V.

Jacdac power delivery is
optional. Spec requires
current limiting with auto
retry, and that nothing gets
hot! This shield delivers
75mA typical, 100mA max.

U3 boosts VUBIT to 4.05V
(which gives 170mV margin)
to provide Jacdac bus power.

ILIM wired to IN sets 75mA
±25mA current limit.

D5 prevents back-powering
U4 from Jacdac bus, but has
forward voltage drop of

A Jacdac supply of up to
100mA must be ≥3.67V at
the connector, i.e. U3
output ≥3.88V. 100mA max
requires 145mA from 3.3V
VUBIT supply. LCD1 takes
45mA to give 190mA total.

This information is provided “as-is”. You
bearthe risk of using it. Some
information relates topre-released
specification which may change without
notice. Microsoft makes nowarranties,
express orimplied, with respectto the
information provided here.

If FAULT is asserted, EN is
taken low. This disables U4
(and clears FAULT). C9/R7
will re-enable the part
after 750ms.

Check Jacdac spec for
voltages required at higher
currents and MCU-based
'smart power providers'.

When this PDF is viewed with Adobe Reader, clicking on
components shows part numbers and other details.

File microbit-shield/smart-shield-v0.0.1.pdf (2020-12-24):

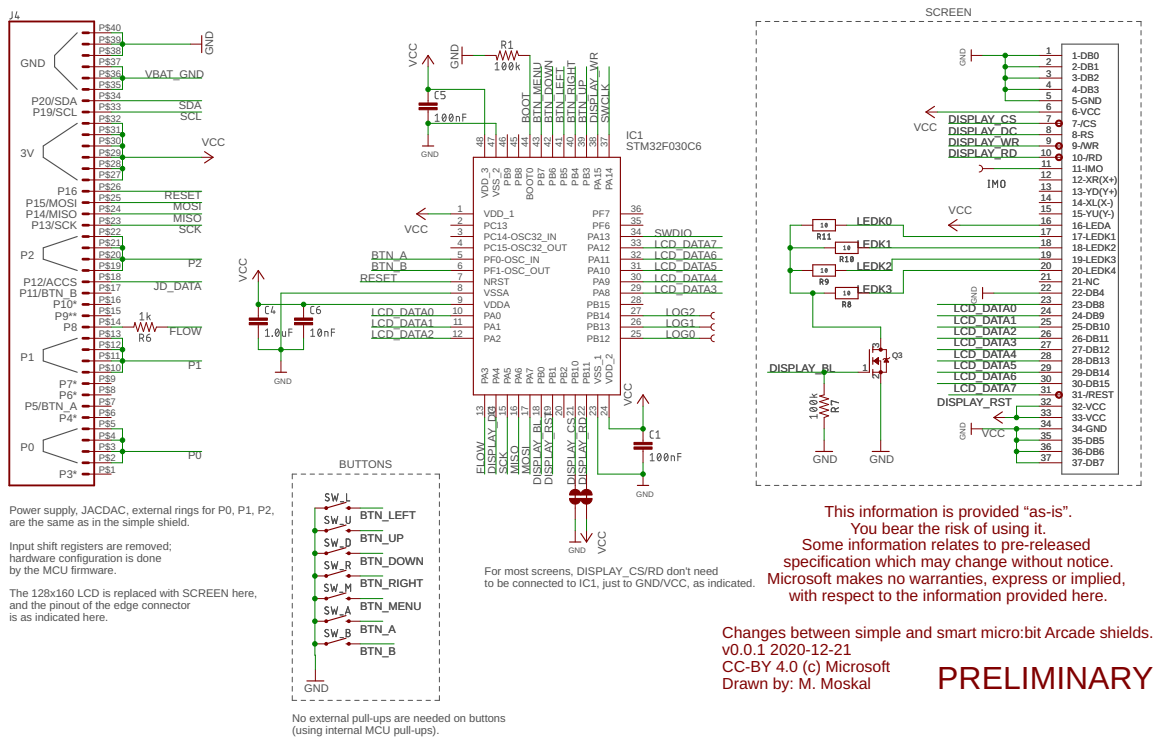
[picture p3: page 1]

GND Power supply, JACDAC, external rings for P0, P1, P2, are the same as in the simple shield.

This information is provided “as-is”. You bear the risk of using it. Some information relates to pre-released

Input shift registers are removed;
hardware configuration is done
by the MCU firmware. The 128x160 LCD is replaced with SCREEN here, and the pinout of the edge connector

specification which may change without notice. Microsoft makes no warranties, express or implied, with respect to the information provided here.

For most screens, DISPLAY_CS/RD don't need
to be connected to IC1, just to GND/VCC, as indicated.

is as indicated here.

Changes between simple and smart micro:bit Arcade shields. v0.0.1 2020-12-21
CC-BY 4.0 (c) Microsoft

No external pull-ups are needed on buttons
(using internal MCU pull-ups).

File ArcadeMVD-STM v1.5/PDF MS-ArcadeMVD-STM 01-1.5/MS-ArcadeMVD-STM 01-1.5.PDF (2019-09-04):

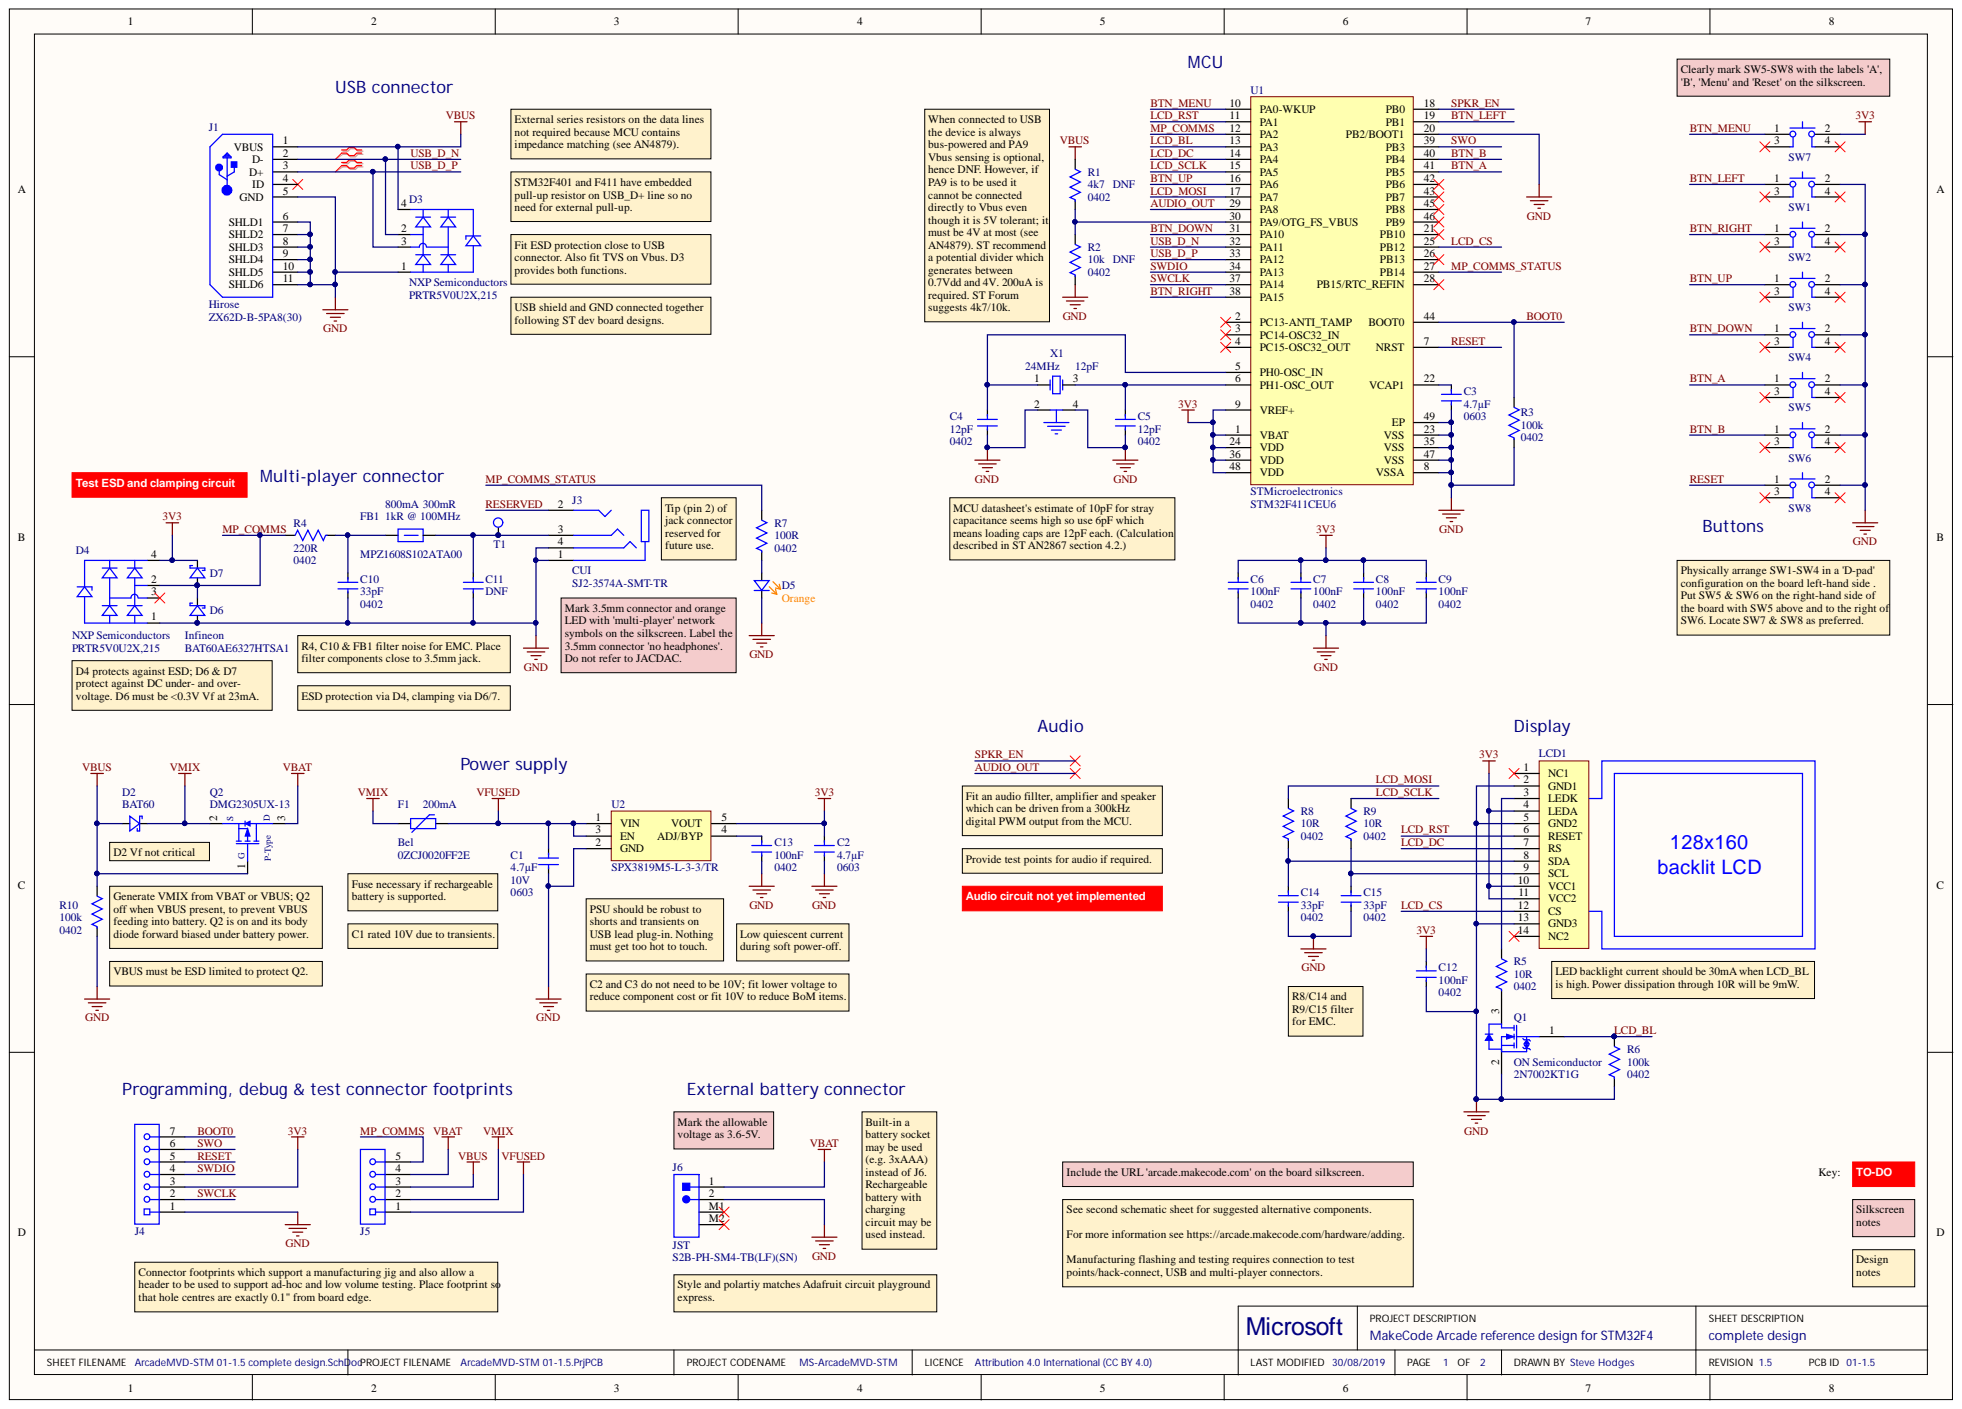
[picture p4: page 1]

Clearly mark SW5-SW8 with the labels 'A',
'B', 'Menu' and 'Reset' on the silkscreen.

External series resistors on the data lines
not required because MCU contains
impedance matching (see AN4879).

When connected to USB
the device is always
bus-powered and PA9
Vbus sensing is optional,
hence DNF. However, if
PA9 is to be used it
cannot be connected
directly to Vbus even
though it is 5V tolerant; it
must be 4V at most (see
AN4879). ST recommend
a potential divider which

STM32F401 and F411 have embedded
pull-up resistor on USB_D+ line so no
need for external pull-up.

Fit ESD protection close to USB
connector. Also fit TVS on Vbus. D3
provides both functions.

USB shield and GND connected together
following ST dev board designs.

Test ESD and clamping circuit

jack connector reserved for future use.

MCU datasheet's estimate of 10pF for stray
capacitance seems high so use 6pF which
means loading caps are 12pF each. (Calculation
described in ST AN2867 section 4.2.)

SJ2-3574A-SMT-TR C6 C7 C8 100nF 100nF 100nF | Physically arrange SW1-SW4 in a 'D-pad' configuration on the board left-hand side . Put SW5 & SW6 on the right-hand side of the board with SW5 above and to the right of SW6. Locate SW7 & SW8 as preferred.

Mark 3.5mm connector and orange
LED with 'multi-player' network
symbols on the silkscreen. Label the
3.5mm connector 'no headphones'.
Do not refer to JACDAC.

R4, C10 & FB1 filter noise for EMC. Place
filter components close to 3.5mm jack.

D4 protects against ESD; D6 & D7
protect against DC under- and over-
voltage. D6 must be <0.3V Vf at 23mA.

ESD protection via D4, clamping via D6/7.

Fit an audio fillter, amplifier and speaker
which can be driven from a 300kHz
digital PWM output from the MCU.

Provide test points for audio if required.

Fuse necessary if rechargeable
battery is supported.

Generate VMIX from VBAT or VBUS; Q2
off when VBUS present, to prevent VBUS
feeding into battery. Q2 is on and its body
diode forward biased under battery power.

Audio circuit not yet implemented

PSU should be robust to
shorts and transients on
USB lead plug-in. Nothing
must get too hot to touch.

C1 rated 10V due to transients.

Low quiescent current
during soft power-off.

VBUS must be ESD limited to protect Q2.

LED backlight current should be 30mA when LCD_BL
is high. Power dissipation through 10R will be 9mW.

C2 and C3 do not need to be 10V; fit lower voltage to
reduce component cost or fit 10V to reduce BoM items.

Include the URL 'arcade.makecode.com' on the board silkscreen.

See second schematic sheet for suggested alternative components.

JST

For more information see https://arcade.makecode.com/hardware/adding.

Manufacturing flashing and testing requires connection to test
points/hack-connect, USB and multi-player connectors.

Connector footprints which support a manufacturing jig and also allow a
header to be used to support ad-hoc and low volume testing. Place footprint so
that hole centres are exactly 0.1" from board edge.

Style and polartiy matches Adafruit circuit playground
express.

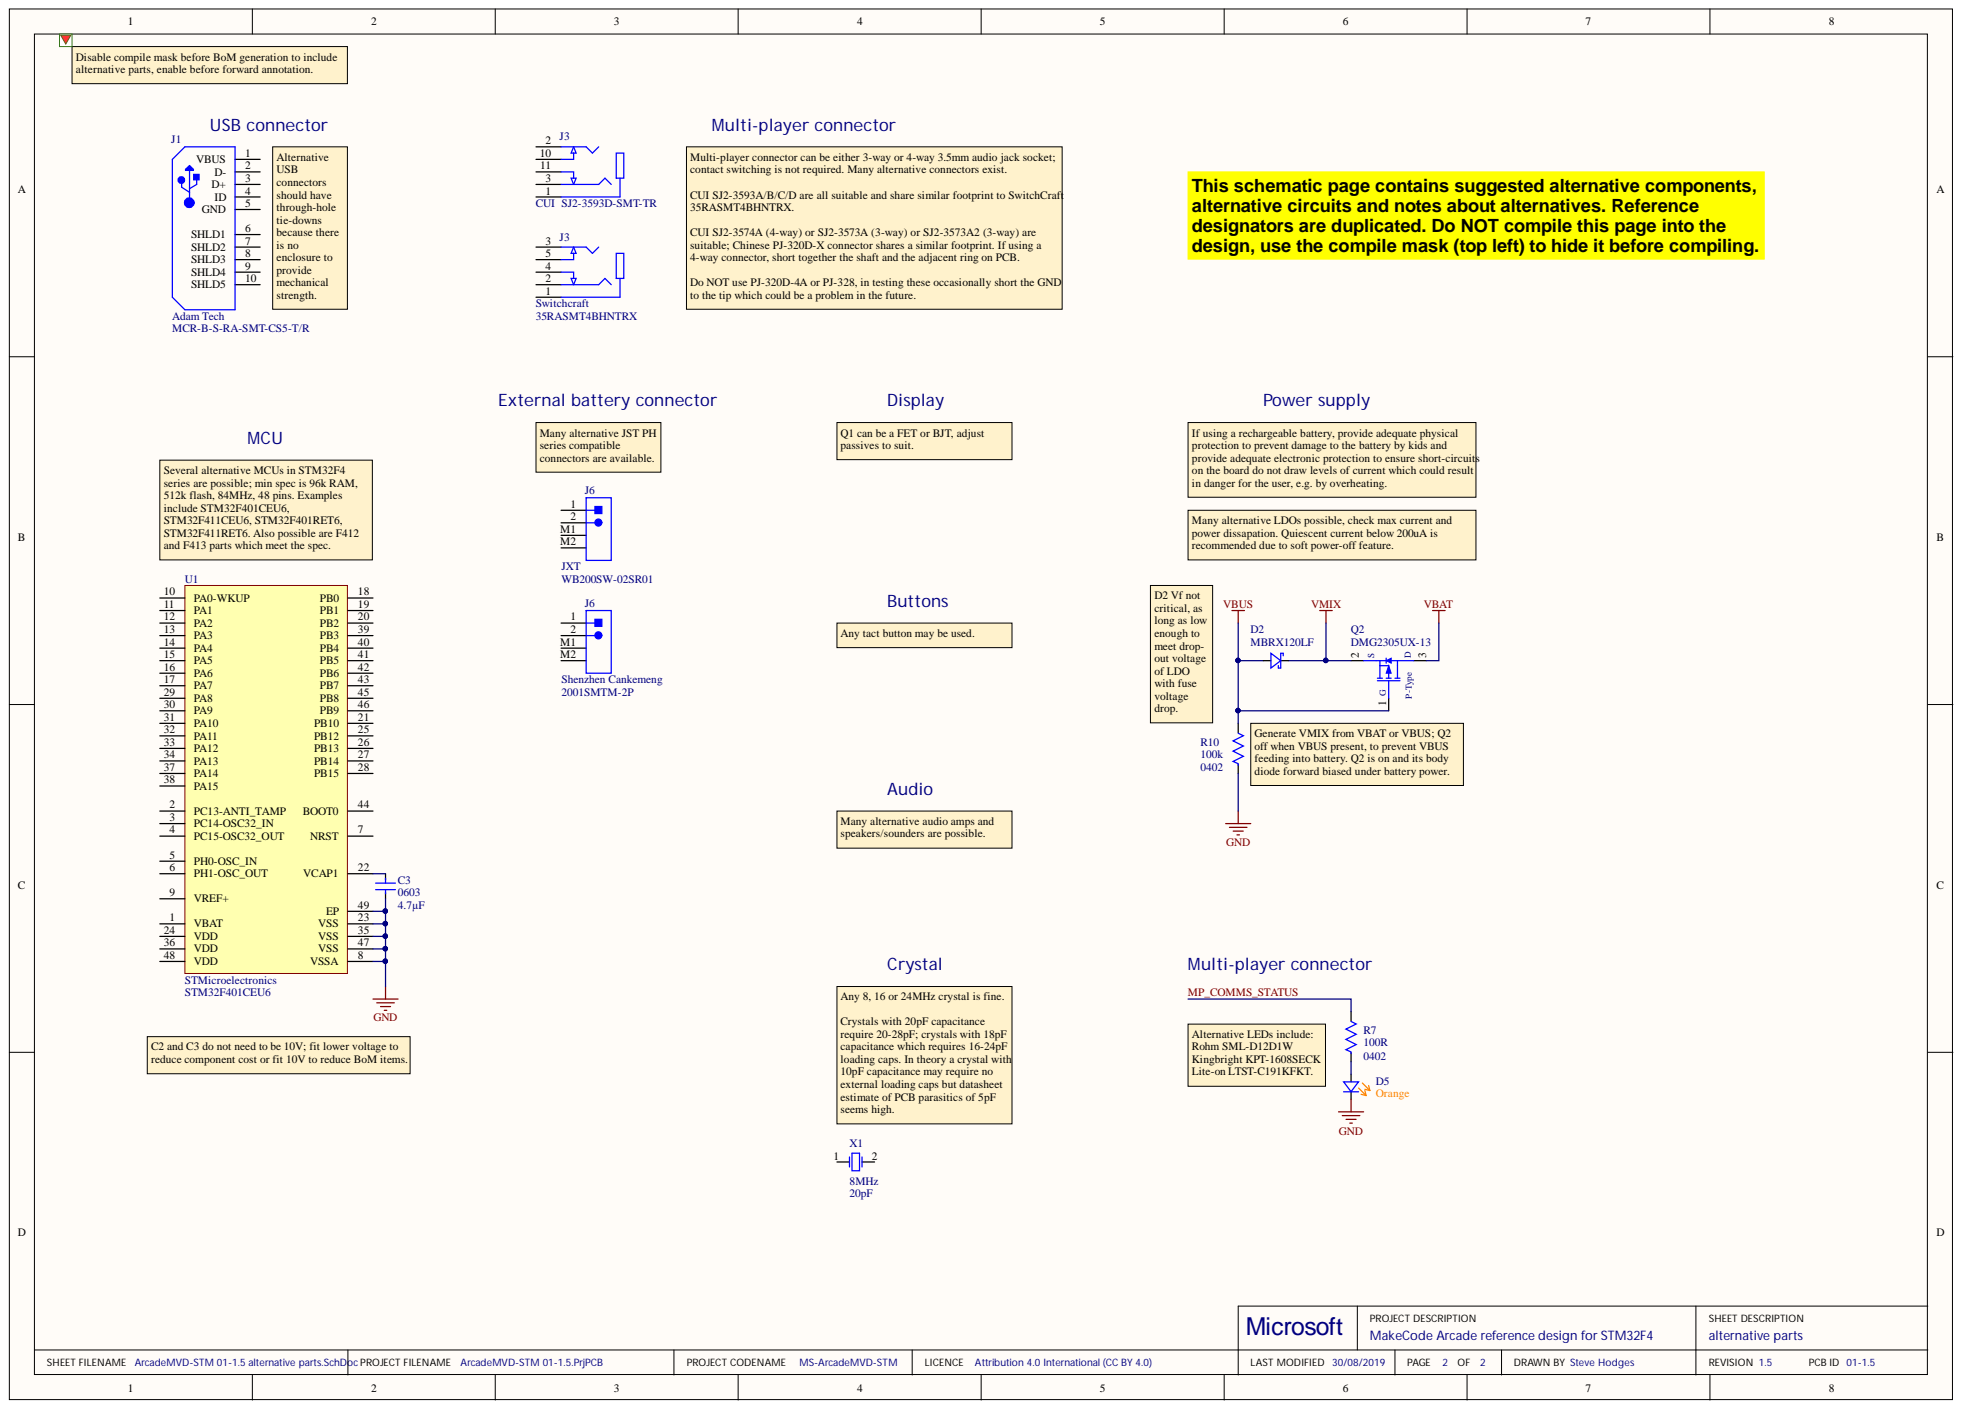
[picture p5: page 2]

le mask before BoM generat

External battery connectorMulti-player connector Many alternat

-player connector can be ei
tching i

his schematic page co

should have through-hole tie-downs

way) or SJ2-3573A (3-
t together the shaft and the adjacent r

plicated. Do NOT co
pile mask (

ip which could be a problem in the future.

protect
provide adequate elect
on the board do not draw level

ion to prevent damage to the bat

tery by kids and
ion to ensure shor
s of cur

in danger for the user, e.g. by overheat

rent which could resul
ing.

ternat
mended due to soft power

ible, check max cur

long as low
enough to meet drop-

ton may be used.

ive audio amps and

C2 and C3 do not need to be 10V
reduce component cos

external loading caps but datasheet
seem

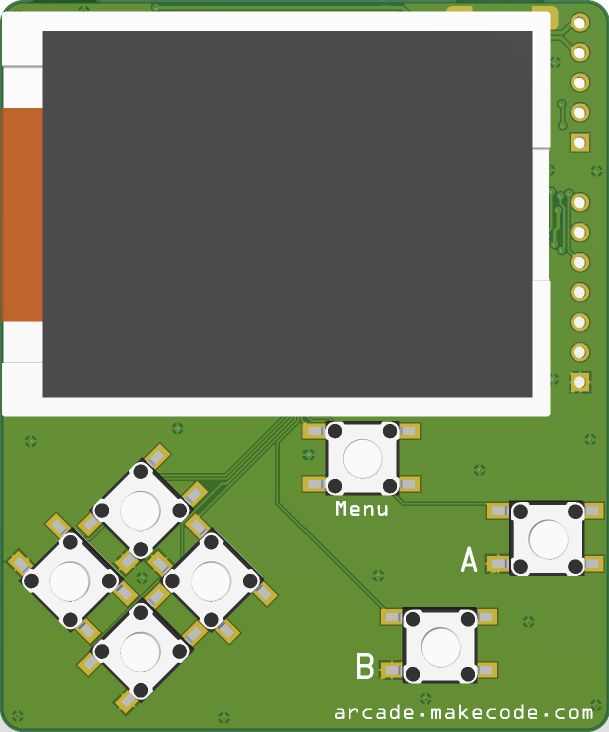
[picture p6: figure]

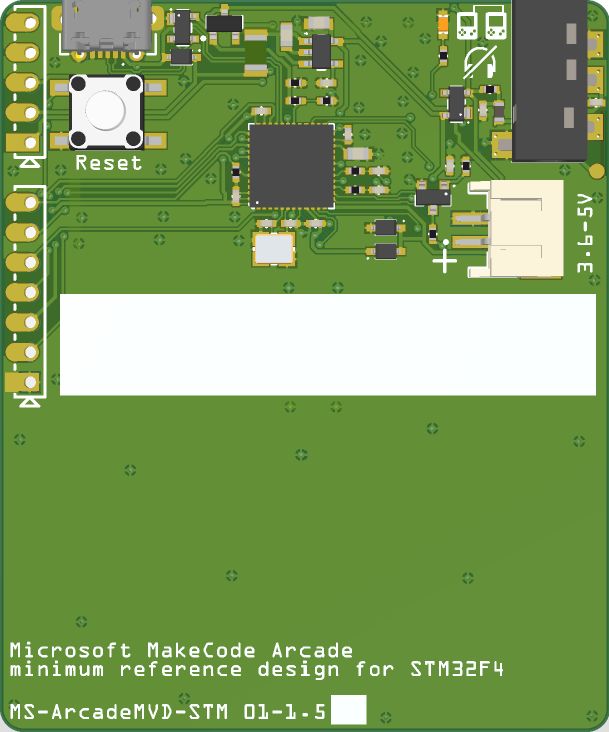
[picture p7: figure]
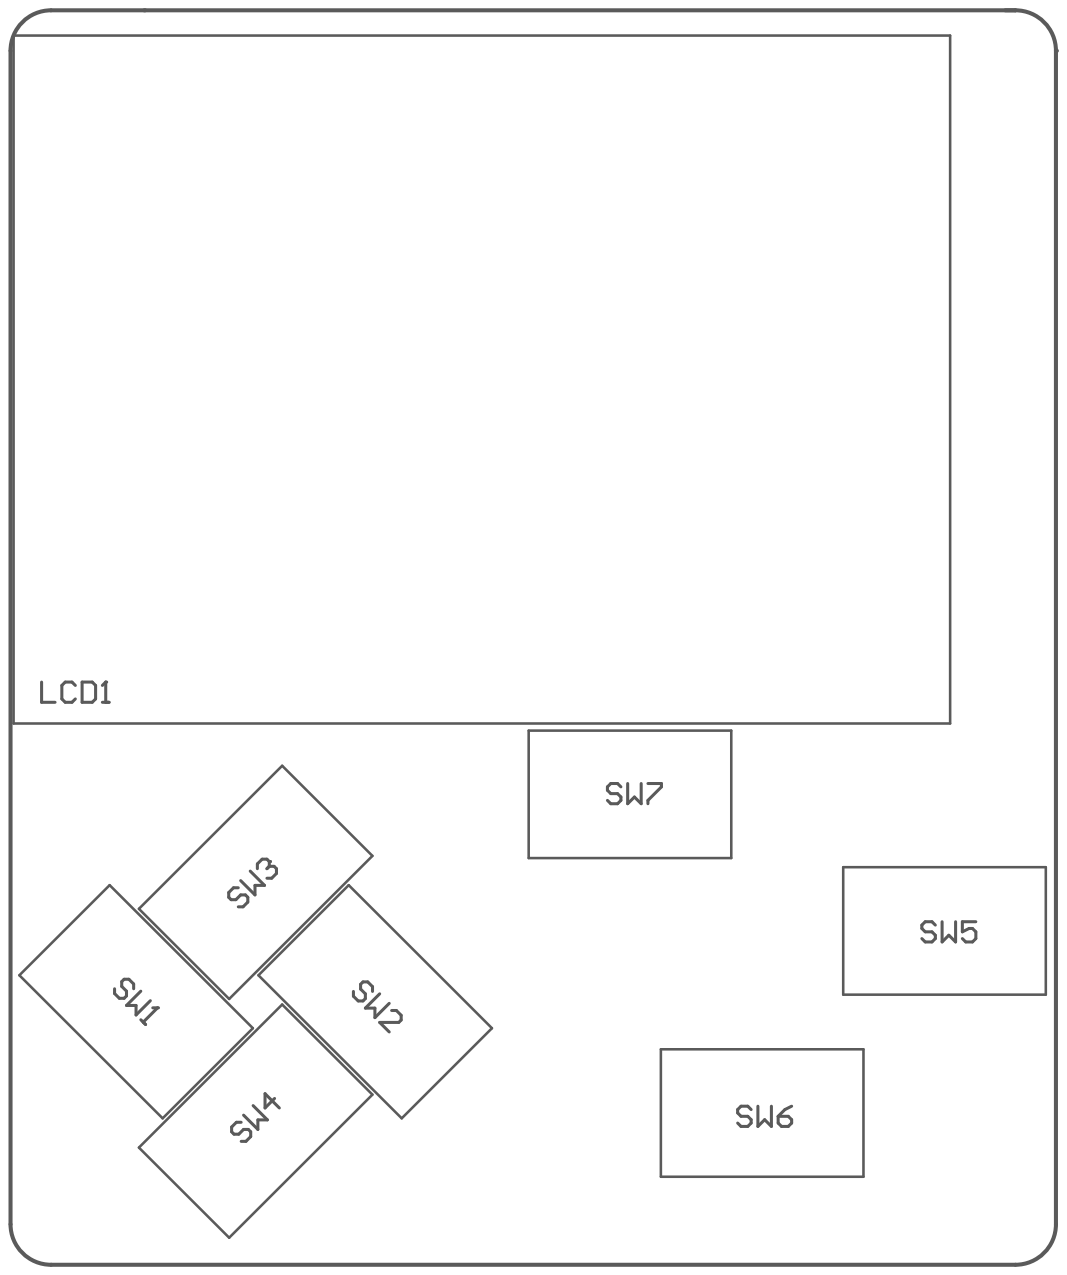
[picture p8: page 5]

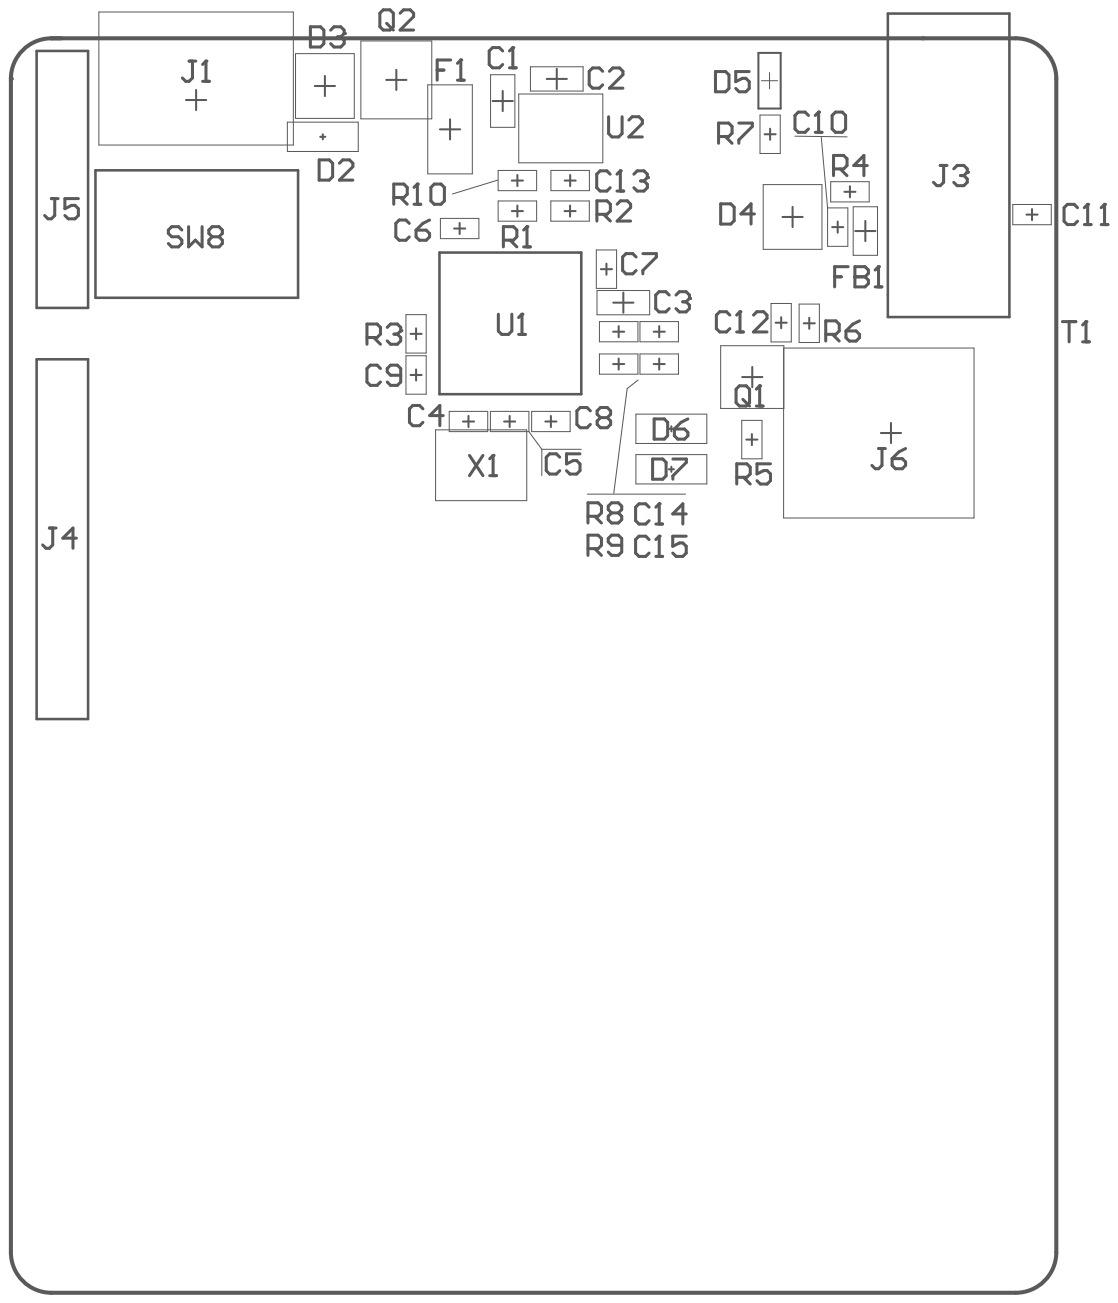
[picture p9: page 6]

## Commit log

2019-08-27 adding ArcadeMVD-STM v1.5 design files for first release
    [ArcadeMVD-STM 01-1.5 alternative parts.SchDoc, ArcadeMVD-STM 01-1.5 complete design.SchDoc, ArcadeMVD-STM 01-1.5.PcbDoc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]
2019-09-04 altered BOOT1 wiring
    [ArcadeMVD-STM 01-1.5 alternative parts.SchDoc, ArcadeMVD-STM 01-1.5 complete design.SchDoc, ArcadeMVD-STM 01-1.5.PcbDoc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]
2020-12-24 adding PDF of Altium schematic and BoM for Simple Shield
    [BOM (complete design) MicroBitArcadeShieldMVD 08-1.1.xlsx]
2020-12-24 Fix BOM link
2024-12-26 added new reference design files
    [BOM (complete design) MicroBitArcadeShieldMVD 08-1.2.xlsx]
2025-01-02 updated v1.2 schematic to fix error
